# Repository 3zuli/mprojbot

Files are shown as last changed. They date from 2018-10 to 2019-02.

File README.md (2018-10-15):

# mprojbot
MPROJ robot project files

## Development

### Version control with git

Recommendation: Use GitKraken, it's free for personal use.

Main principles:
* master branch is (mostly) stable
* development is done on "feature" (or "topic") branches
* ideal rule: one "feature" = one commit
* avoid merge commits, rebase before merge

#### Feature branch
A "feature" or "topic" branch should concentrate on solving one specific task.
It can be a bug fix, a new feature, or new documentation. This should help
to better split the work for multiple developers and to create less merge
conflicts when integrating the work into the master.

Lifecycle:

1. create a feature branch from the actual master
```sh
git checkout master
git pull origin master
git checkout -b <feature_branch>
```

2. continously commit related changes, rebase to the actual master
```sh
git add ...
git commit -m ...
git pull --rebase origin master
```

3. push the branch to github and create a pull request
```sh
git push --set-upstream origin <feature_branch>
```

4. merge to master
```sh
git checkout master
git merge <feature_branch>
git push
```

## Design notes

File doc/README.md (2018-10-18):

# Place documentation, datasheets, schematics etc. here

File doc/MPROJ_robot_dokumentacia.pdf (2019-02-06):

# Manažment projektov

## Robot pre súťaž Istrobot

Bc. Eduard Mráz

Bc. Adam Trizuljak

Bc. Dominik Varga

Bc. Ondrej Zsíros

Bc. Michal Nagy

Bc. Michal Hubík

# 1 Obsah

1 Obsah | 2
2 Úvod | 3
3 Opis robota | 4
3.1 Vysokoúrovňová časť | 4
3.2 Nízkoúrovňová časť | 4
4 Konštrukcia | 6
5 Nízkoúrovňové riadenie | 10
5.1 Spracovanie senzorov | 10
5.2 Riadenie motorov a odometria | 12
6 Vysokoúrovňové riadenie | 13
6.1 Vizuálny systém robota | 14
6.1.1 Detekcia čiary z obrazu kamery | 14
6.1.2 Určenie regulačnej odchýlky | 15
6.1.2.1 Určenie stredu čiary z obrazu kamery | 16
7 Prepojenie oboch úrovní riadenia | 17
7.1 Komunikačný protokol RPi <-> Nucleo | 18
8 User stories | 19
8.1 User stories riešené v rámci semestra | 19
8.2 Dodatočné user stories pre potreby súťaže Istrobot | 20
9 Záver | 21

# 2 Úvod

Cieľom tohto projektu je navrhnúť, vytvoriť a spojazdniť model robota pre súťaž Istrobot. Súťažnou kategóriou bude Stopár. Robot, ktorý sa zúčastní tejto kategórie by mal byť schopný autonómneho pohybu po určenej dráhe a v časovom limite prísť do cieľa. Smer a trasa je daná tmavým pruhom na bielom podklade, pričom na dráhe sú umiestnené rozličné prekážky, napr. tehla, záclona a mostík. Robot je taktiež limitovaný šírkou a výškou, ktoré nesmú presiahnuť 20 centimetrov.

Výsledkom projektu bude model robota, ktorý bude schopný pohybu po zvolenej dráhe. Bude obsahovať nízko úrovňové a vysoko úrovňové riadenie. Bude obsahovať všetky komponenty potrebné pre zdolanie všetkých prekážok súťaže v danej kategórií. Detegovanie čiary bude zabezpečené pomocou jednoduchého vizuálneho systému.

Nakoľko je súťaž až v nasledujúcom semestri, robot na ňu nemusí byť plne pripravený v čase odovzdávania tohto projektu. A teda ďalšou prácou pre splnenie podmienok súťaže Istrobot, bude tvorba ďalších algoritmov na zdolávanie jednotlivých prekážok.

# 3 Opis robota

Pri návrhu koncepcie sme robota rozdelili na dve základné časti, ktoré medzi sebou komunikujú prostredníctvom sériovej komunikácie, a to vysokoúrovňová časť a nízkoúrovňová časť. Obe tieto časti sú umiestnené na samostatnej doske, kde majú k sebe pripojené senzory potrebné pre súťaž Istrobot.

## 3.1 Vysokoúrovňová časť

Ako už bolo spomenuté robot bude súťažiť v kategórií Stopár, kde musí sledovať čiernu čiaru. Na detekovanie čiary musí byť robot vybavený senzorom, ktorý bude schopný čiaru rozlíšiť oproti bielej podložke. My sme si zvolili kameru RASPBERRY Pi Camera Board, ktorá je doplnená o osvetlenie pre prekážku tunel. Kamera je pripojená cez rozhranie CSI k výpočtovej jednotke Raspberry Pi Model 2.

Okrem výpočtovej jednotky a kamery je vo vysokoúrovňovej časti zabudovaný aj napäťový regulátor, ktorého vstupom je napätie akumulátora a výstupom je stabilizované napätie 5V, ktoré slúži na napájanie RPi a mikroprocesora v nízkoúrovňovej časti. Regulátor je umiestnený zo spodnej strany dosky. Pre lepšiu manipuláciu s robotom sme do vysokoúrovňovej časti umiestnili aj vypínač, ktorý odpája napájanie motorov.

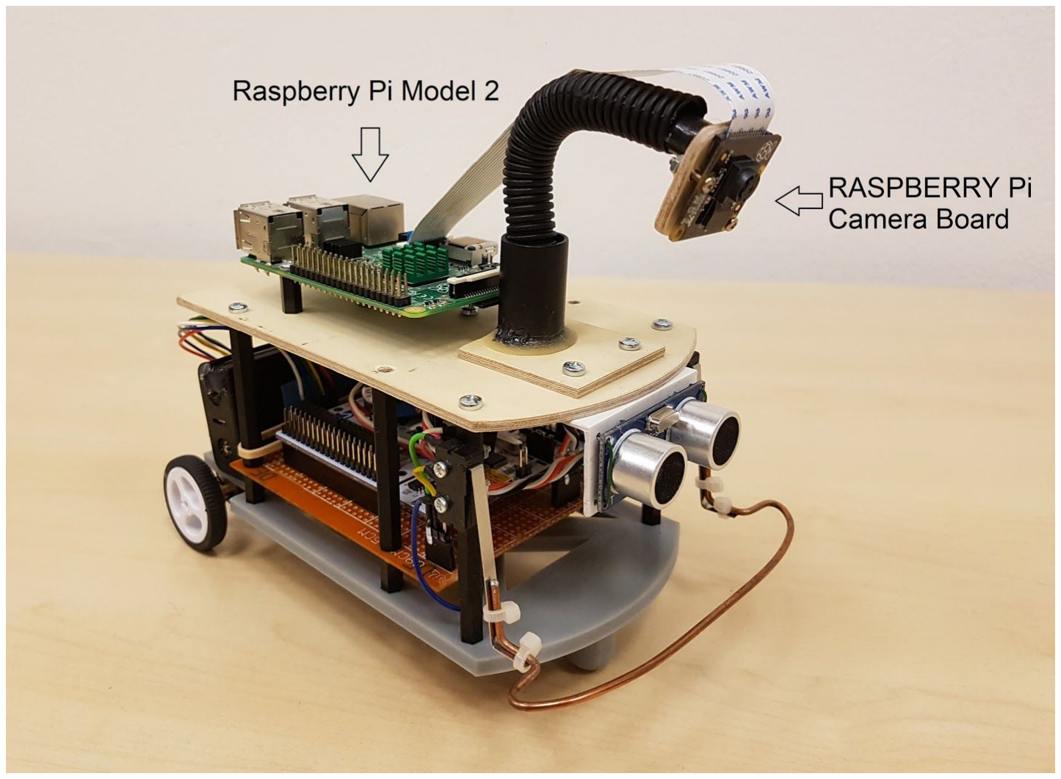
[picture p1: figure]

## 3.2 Nízkoúrovňová časť

Sériovou komunikáciou vysokoúrovňová časť posiela signály do nízkoúrovňovej časti konkrétne do vývojovej jednotky Nucleo64-F411RE, ktoré súčasťou je mikroprocesor

STMicroelectronics STM32F411. V mikroprocesore signály poslané vysokoúrovňovou časťou spracujú a vyhodnotia sa potrebné uhlové rýchlosti otáčania oboch kolies. Signál určujúci veľkosť uhlovej rýchlosti kolies sa pošle do budiča motorov, ktorý reguláciou napájacieho napätia motorov určí ich výslednú rýchlosť otáčania. Regulácia napätia je uskutočňovaná pulzne šírkovou moduláciou.

Keďže jedna z prekážok na súťaži je tehla (tehla položená cez čiernu čiaru) robot musí vedieť obísť túto prekážku. Na to nám slúžia dva typy senzorov - ultrazvukový snímač a tlačidlový spínač na prednom nárazníku. Keď sa robot bude približovať k tehle kamera nebude môcť detekovať čiaru. Robot sa bude pohybovať ďalej ale čím bližšie bude k tehle tým pomalšie pôjde. Toto spomaľovanie spôsobuje ultrazvukový snímač, ktorý spomaľuje robota až kým nepríde k tehle. Akonáhle robot narazí na tehlu zopnú sa tlačidlové spínače na nárazníku a robot začne prekážku obchádzať. Po obídení prekážky kamera znova začne detekovať čiaru a robot pokračuje ako doposiaľ. Na rovnakom princípe sa robot bude pohybovať aj pri prekážke typu záclona, kde robot bude spomaľovať ako sa bude približovať k záclone. Keďže záclona nie je pevná prekážka, tlačidlové snímače sa nezopnú a robot bude pomaly pokračovať cez záclonu až kým sa robot znovu nezrýchli za prekážkou.

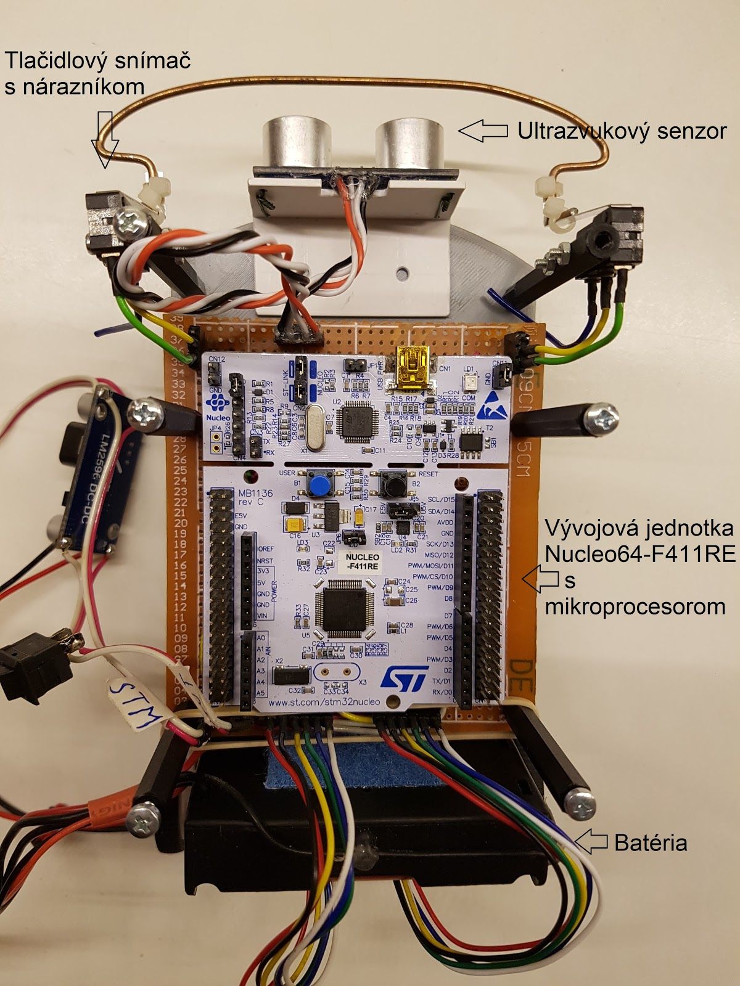
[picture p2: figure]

# 4 Konštrukcia

Po koncepčnom návrhu jednotlivých funkcionalít, potrebných pre úspešné prejdenie celého súťažného kola súťaže Istrobot v kategórii Stopár, vrátane všetkých špecifikovaných prekážok, bolo potrebné navrhnúť fyzickú konštrukciu celého robota.

Najzákladnejším parametrom konštrukcie, ktorý bolo potrebné stanoviť ako prvý, boli vonkajšie rozmery, čiže dĺžka, šírka a výška. Azda najviac limitujúcim faktorom na súťažnej dráhe je prekážka “Tunel”, ktorá má vstupný otvor rozmerov 20x20cm. Pre úspešné prejdenie tejto prekážky je potrebné aby robot vošiel do tunela - jeho šírka a výška musia byť menšie ako 20cm, a zároveň dokázal v neosvetlenom priestore sledovať čiaru. My sme sa rozhodli zvoliť celkovú šírku 12cm. Táto šírka plne postačuje na dostatok priestoru pre všetky komponenty a zároveň poskytuje dostatočnú rezervu pre vstup do tunela bez prípadnej kolízie z dôvodu nepresnosti riadenia. Dĺžku robota sme po rýchlom prototypovaní - pokusné rozmiestňovanie jednotlivých komponentov na čo najmenšej ploche, zvolili 25 centimetrov. Dĺžka robota nie je obmedzená žiadnou prekážkou, no nemala by byť príliš veľká z dôvodu možných problémov napríklad pri obchádzaní prekážky “Tehla” alebo pri prejazde zatáčok s malým polomerom. Na výslednú dĺžku mali vplyv hlavne rozmery riadiacich dosiek, akumulátorov, motorov a nárazníka.

Po stanovení rozmerov bolo potrebné zvoliť typ podvozku robota. Najčastejšie sa v tejto súťaži vyskytujú dvojkolesové alebo štvorkolesové diferenciálne podvozky. Po uvážení faktorov ako napríklad:

- Celková hmotnosť
- Rozmery a potrebná kapacita akumulátorov
- Náročnosť konštrukcie
- Cena komponentov
- Zložitosť riadenia

sme sa rozhodli pre dvojkolesový diferenciálny podvozok v jedným oporným kolesom. Konfigurácia kolies je nasledovná:

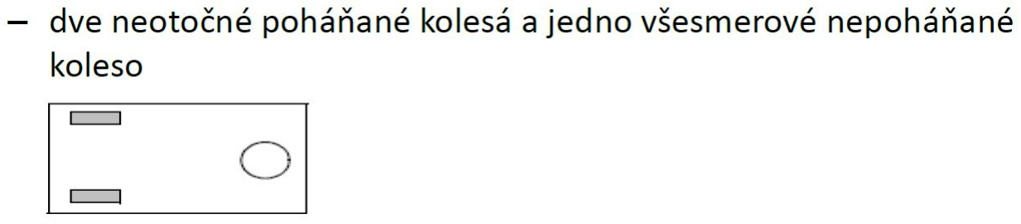
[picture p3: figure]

Po zvolení koncepcie podvozku, bolo potrebné navrhnúť jeho konštrukciu. Po zvážení rôznych konštrukčných požiadaviek sme sa rozhodli vytvoriť základnú podvozkovú dosku formou návrhu 3D modelu a následnej 3D tlače z plastu typu PLA. Voľbou tohto postupu sme zabezpečili nízku hmotnosť, dostatočnú pevnosť a tiež presnosť upevnení motorov. Presnosť bola veľmi dôležitým faktorom, nakoľko sa oba motory (obe osi kolies) musia z dôvodu požadovanej trajektórie podvozku nachádzať na jednej osi. To zabezpečí možnosť priamočiareho pohybu ako aj otáčania na mieste. Okrem dier potrebných k upevneniu motorov obsahuje táto základná doska aj diery potrebné pre uchytenie dištančných stĺpikov. Na tie sa následne montovala doska nízkoúrovňového a vysokoúrovňového riadenia. Zároveň dva predné stĺpiky slúžia aj na uchytenie mikrospínačov nárazníka v požadovanej výške 75 mm od zeme. Na uchytenie vypínačov poslúžili krížové skrutky M2 x 15 mm. K základnej doske je nad osou motorov pripevnený pomocou suchého zipsu pohonný akumulátor tvorený dvoma Li-Ion článkami typu 18650 akumulátorov a pre istotu je jeho pozícia fixovaná pomocou gumičky o zadné dištančné stĺpiky.

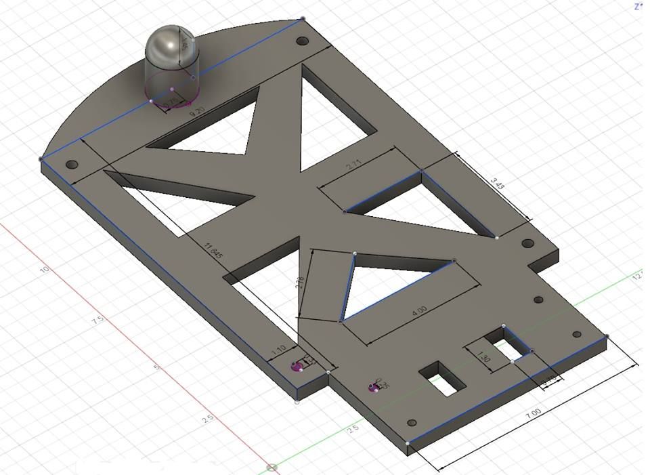
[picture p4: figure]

3D CAD model podvozku robota

Po vytlačení a opracovaní hrán základnej dosky sme ako prvé pripevnili motory - konkrétne sme zvolili jednosmerné motory s nasledovnými parametrami:

- Rýchlosť: 90 otáčok/min.
- Napájacie napätie: 6V
- Prevodový pomer prevodovky: 100:1
- Krútiaci moment (kg.cm): 0.7
- Elektrický prúd (mA): ≤170
- Počet impulzov na jednu otáčku kolesa: 2800

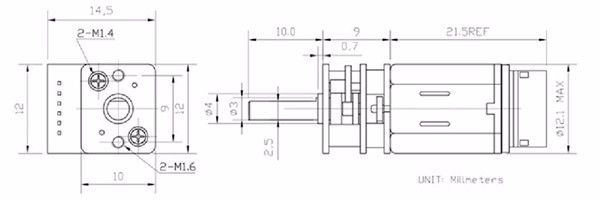
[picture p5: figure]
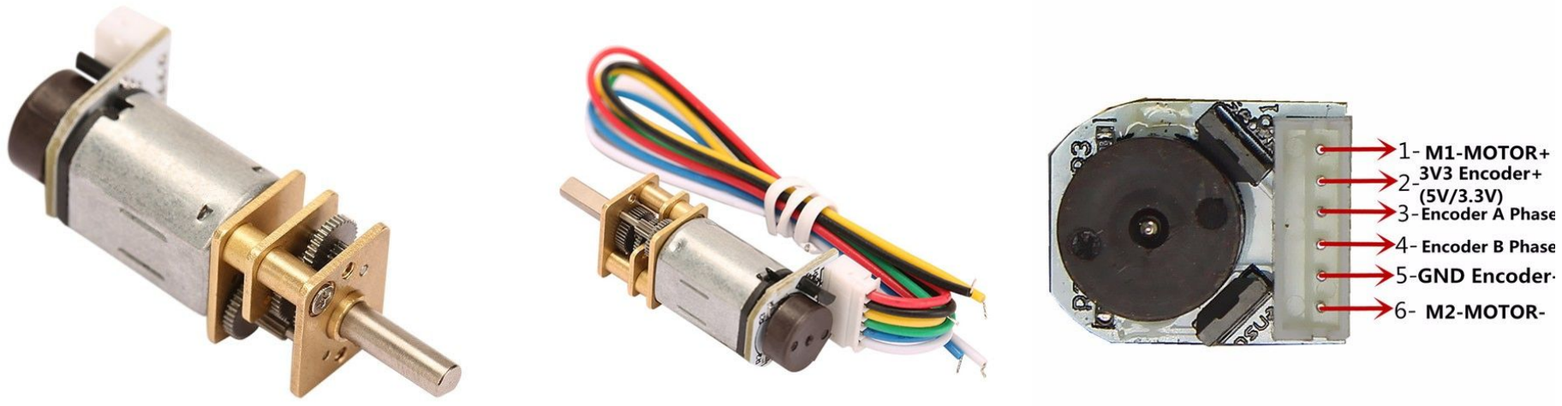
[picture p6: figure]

Po primontovaní kolies s priemerom 35mm na hriadele prevodovky bol v podstate dokončený celý podvozok. Následne sme na základnú dosku pripevnili prvé dištančné stĺpiky s dĺžkou 11 mm na ktoré bola upevnená univerzálna doska plošných spojov - DPS, s rozmermi 10 x 9 centimetrov. Táto doska - nazývaná aj ako “doska nízkoúrovňového riadenia”, obsahuje:

- Päticu pre mikrokontrolér
- Mikrokontrolér STM Nucleo F411RE
- 2x dolnopriepustný filter pre spínače nárazníka
- Napájacie a komunikačné konektory
- Driverovú dosku zabezpečujúcu chod motorov
- Kabeláž periférii k nízkoúrovňovému mikrokontroléru

Keďže by sa na jedno podlažie robota všetky potrebné súčiastky nezmestili, bolo potrebné navrhnúť a vyrobiť aj druhé podlažie, kam by sa umiestnili zvyšné súčiastky.

Ako nosnú konštrukciu druhého podlažia robota sme opäť zvolili plastové dištančné stĺpiky dĺžky 50mm, na ktoré sme umiestnili z leteckej preglejky hrúbky 3mm vyrezávanú dosku v tvare základnej dosky podvozku. Dosku druhého podlažia nazývame aj doska vysokoúrovňového riadenia. Do nej sme následne vŕtaním vyrobili diery potrebné pre uchytenie následných komponentov:

- Napäťový regulátor
- Mikropočítač Raspberry Pi 2
- Kolískový vypínač napájania motorov
- Držiak vizuálneho systému + vizuálny systém

- Ultrazvukový senzor

Použitý napäťový regulátor LM2596 DC-DC slúži na konvertovanie vstupného jednosmerného napätia z akumulátora na stabilizované napätie 5V potrebné na napájanie oboch dosiek riadenia. Jeho uchytenie je realizované dištančnými stĺpikmi. Kolískový vypínač umiestnený vedľa mikropočítača Raspberry Pi z hornej strany dosky slúži na prerušenie napájania driverovej dosky - robot sa prestane hýbať. Držiak kamery je umiestnený v prednej časti hornej dosky, a poskytuje 6 stupňov voľnosti pri nastavovaní polohy a orientácie kamery. Kamera je k držiaku pripevnená dvomi krížovými skrutkami M2x20 mm Na záver je horná doska upevnená k dištančným stĺpikom krížovými skrutkami M3 x 20mm.

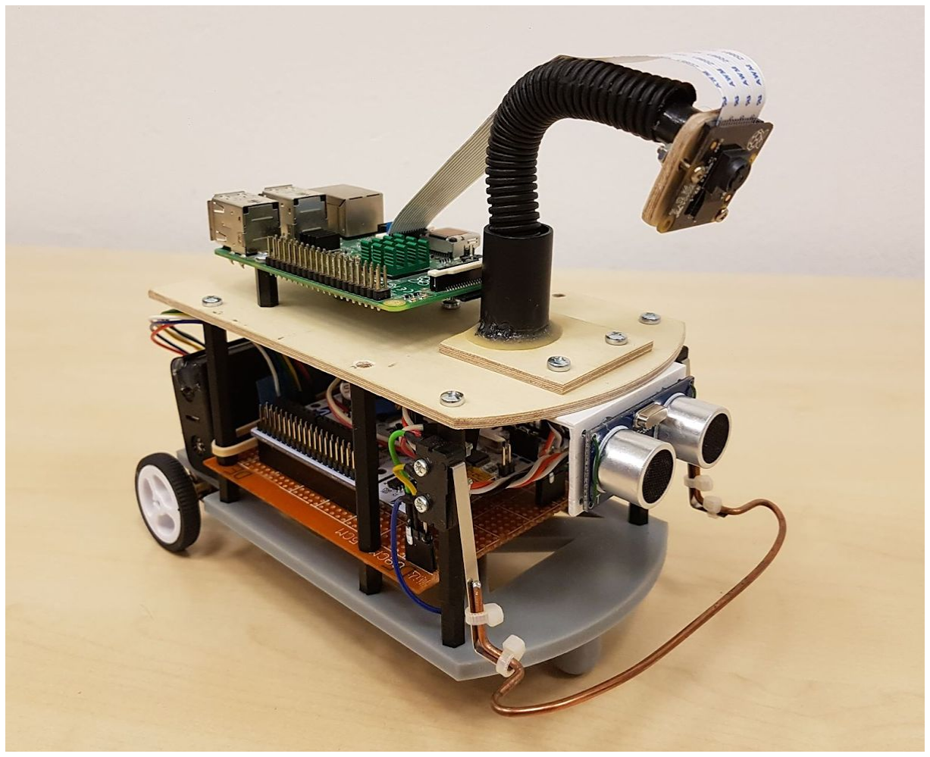
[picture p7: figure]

# 5 Nízkoúrovňové riadenie

Nízkoúrovňové riadenie prijíma príkazy z vysokoúrovňového riadenia prebiehajúceho v Raspberry Pi a zabezpečuje predovšetkým riadenie rýchlosti motorov. Taktiež počíta aktuálnu odometriu, spracováva údaje zo senzorov a odosiela ich do Raspberry Pi, kde prebieha ich vyhodnotenie.

Riadenie je realizované mikroprocesorom STMicroelectronics STM32F411 (ďalej len STM), čo je 32-bitový ARM Cortex-M4 procesor s frekvenciou 100MHz, s 512KB programovej pamäte a 128KB RAM. Tento procesor je súčasťou vývojovej dosky Nucleo64-F411RE, ktorá obsahuje aj programátor/debugger s USB rozhraním pre jednoduché a pohodlné programovanie.

Po spracovaní senzorov sa výsledné údaje spolu s údajmi odometrie odosielajú po sériovej linke do Raspberry Pi.

## 5.1 Spracovanie senzorov

Mikroprocesor realizuje spracovanie dát z nasledovných senzorov:

- 2x inkrementálny enkóder snímajúci otáčky motorov
- 2x tlačidlový spínač predného nárazníku
- Ultrazvukový senzor vzdialenosti HC-SR04

Tlačidlá nárazníku sú pripojené na dva digitálne vstupy. Program v hlavnej riadiacej slučke periodicky číta ich logické hodnoty (0/1).

Inkrementálne enkódery merajú aktuálnu rýchlosť otáčania motorov, ktorá sa používa na PID reguláciu rýchlosti a výpočet odometrie. Enkódery generujú 7 pulzov na otáčku motora, čo na výstupe prevodovky 100:1 dáva 700 pulzov na otáčku kolesa. Tieto pulzy sú automaticky počítané časovačmi TIM4 a TIM5, ktoré sú použité v režime enkóderového rozhrania. Časovače sú nastavené na režim snímania 4x (počíta sa nábežná aj dobežná hrana oboch signálov enkóderu), celkovo teda máme rozlíšenie 2800 pulzov na otáčku kolesa. Uhlovú rýchlosť motorov získame z rozdielu aktuálnej a predošlej hodnoty časovača.

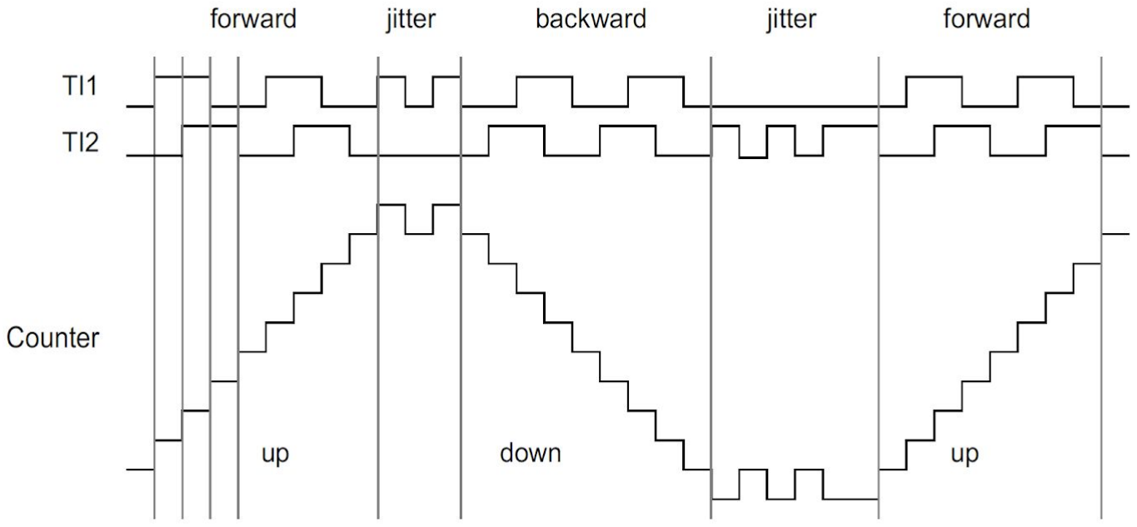
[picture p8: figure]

Hodnota časovača v režime enkóderového rozhrania. TI1,2 - kvadratúrny výstup enkódera, Counter - hodnota počítadla

Výstup ultrazvukového senzora je pulz (ECHO), ktorého dĺžka je rovnaká ako čas od vyslania ultrazvukového pulzu po jeho prijatie. Na presné meranie času je použitý časovač TIM2 v režime počítania nahor s frekvenciou 10MHz, čo zodpovedá časovému rozlíšeniu 0.1μs. Funkcia pre meranie vzdialenosti najprv vyšle do senzoru štartovací pulz (TRIGGER) s dĺžkou 10μs. Následne sa v prerušení čaká na nábežnú hranu signálu ECHO, kde sa vynuluje a spustí časovač. S príchodom dobežnej hrany sa v prerušení zastaví časovač TIM2 a z jeho hodnoty (TIM2CNT) sa vypočíta nameraná vzdialenosť v metroch podľa vzťahu

d = 58000

TIM2CNT

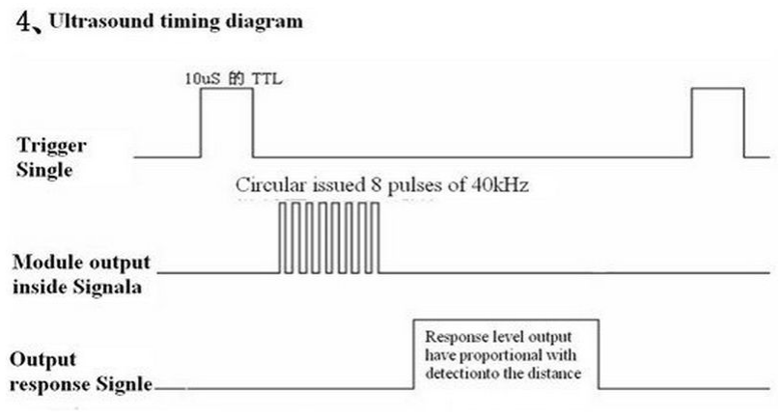
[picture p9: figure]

Časový priebeh komunikácie ultrazvukového senzoru

## 5.2 Riadenie motorov a odometria

Kvôli meniacemu sa napätiu batérie a rôznemu sklonu trate (na mostíku) je potrebné zabezpečiť aktívne spätnoväzobné riadenie rýchlosti motorov. Na tento účel je použitý PID regulátor rýchlosti motorov.

Výstupom vysokoúrovňového riadenia je požadovaná dopredná rýchlosť v a uhlová rýchlosť ω . Z toho vypočítame žiadané uhlové rýchlosti ľavého a pravého motora ωL

, ωR podľa
vzťahov

kde d je vzdialenosť kolies od ťažiska robota a r je polomer kolies.

Riadenie prebieha s frekvenciou 250Hz a je vykonávané pre oba motory samostatne. Vstupom je žiadaná rýchlosť kolesa v radiánoch za sekundu a aktuálna rýchlosť motora získaná z enkóderov, z ktorých sa vypočíta regulačná odchýlka. Hodnota integračnej zložky regulátora je obmedzená na rozsah (-1;1), aby sa zabránilo windupu. Výstupom je bezrozmerný riadiaci signál u v rozsahu (-1;1), kde 0 znamená zastavené motory, 1 je maximálna rýchlosť vpred a -1 je maximálna rýchlosť vzad. Táto hodnota je následne prepočítaná na číslo v rozsahu (0;4095), ktoré udáva striedu pulzne šírkovej modulácie (PWM), ktorou je ovládaná rýchlosť motorov. Celková schéma regulátora je na nasledujúcom obrázku.

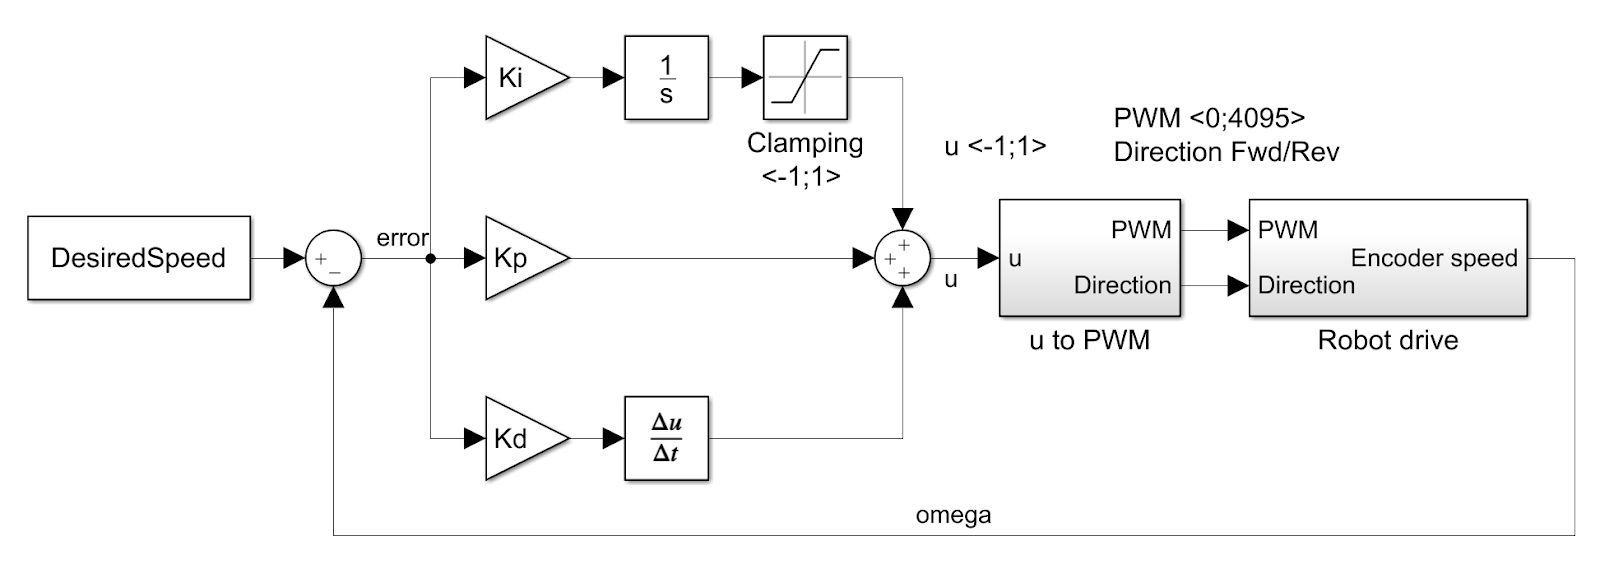
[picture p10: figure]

Schéma PID regulátora rýchlosti motorov

Súčasne s regulátorom prebieha aj výpočet odometrie. Odometria poskytuje odhad aktuálnej polohy a otočenia robota v priestore na základe rýchlosti otáčania kolies. Na nasledujúcom obrázku je znázornená kinematická štruktúra dvojkolesového diferenciálneho podvozku, kde
v je dopredná rýchlosť, φ je aktuálny uhol otočenia, | je vzdialenosť kolies, | je polomer R | d | R
kolies, | sú uhlové rýchlosti motorov a xR
, yR ω , ω | sú aktuálne súradnice ťažiska robota. L | R

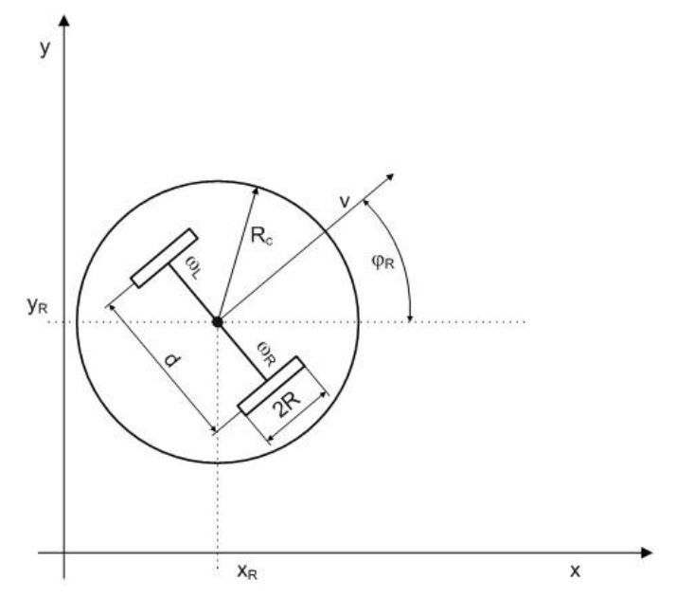
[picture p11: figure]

Výpočet odometrie je realizovaný nasledovnými vzťahmi:

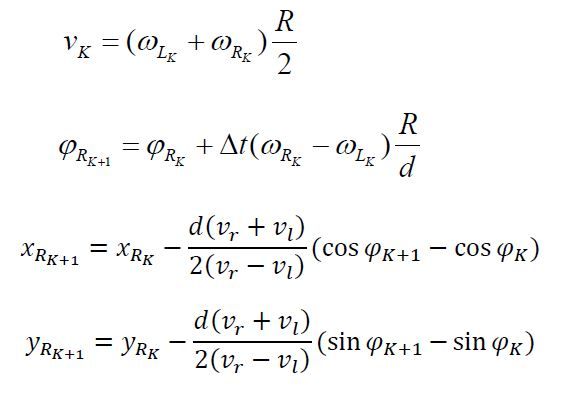
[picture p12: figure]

V prípade, ak sú obe rýchlosti motorov rovnaké:

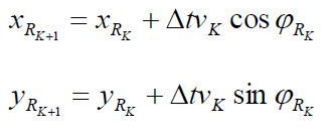
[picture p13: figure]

# 6 Vysokoúrovňové riadenie

Náš robot používa vizuálny systém, a teda pracuje s videom v pomerne vysokej frekvencii. Zatiaľ je FPS (z ang. Frames Per Second - snímky za sekundu - frekvencia spracovania obrazu) nastavené na hodnotu 10. Kvôli tomuto je nutné použiť ďalšiu výpočtovú jednotku, keďže mikroprocesor, ktorý zabezpečuje nízko-úrovňové riadenie by takáto úlohu nezvládal.

Ako výpočtovú jednotku pre vysoko úrovňové riadenie sme zvolili Raspberry Pi Model 2 (ďalej v dokumente len RPi). disponuje procesorom so štyrmi jadrami o takte 900 MHz a 1 GB operačnej pamäte.

V tejto úrovni riadenia budú riešené nasledovné úlohy:

- Spracovanie obrazu z kamery
- Detekcia čiary z obrazu kamery
- Riadiaci algoritmus - výpočet regulačnej odchýlky a výpočet akčného zásahu

## 6.1 Vizuálny systém robota

Vizuálny systém robota je pomerne jednoduchý, keďže ako senzor používa len jeden prvok, a tým je kamera, ktorá je pripojená k RPi. Kamera, ktorú náš systém využíva má názov RASPBERRY Pi Camera Board a je to kamera určená na používanie priamo s RPi. K RPi sa pripája pomocou rozhrania CSI. Dokáže vyhotoviť video s FULL HD rozlíšením a 30 FPS. Tieto parametre su pre nás plne postačujúce, keďže hodnoty FPS aj rozlíšenie sú v našom prípade nižšie - rozlíšenie používame 320x240px a FPS s hodnotou 10.

Ako nástroj pre softvérový prístup ku kamere a získanie snímok z nej používame známu knižnicu OpenCV v prostredí programovacieho jazyka Python. Detekciu čiary na snímkach z kamery taktiež realizujeme pomocou nástrojov z knižnice OpenCV.

### 6.1.1 Detekcia čiary z obrazu kamery

Čiaru z obrazu kamery dokážeme pomerne jednoducho identifikovať pomocou klasických deterministických metód počítačového videnia. Je to najmä vďaka faktu, že pri kategórii LineFollower v súťaži Istrobot je čiara viditeľná veľmi zreteľne - čiara je čierna na čisto bielom podklade.

v prvej fáze tejto úlohy potrebujeme vytvoriť binárnu masku, kde biele pixely (pixely s hodnotou 1) budú predstavovať časť obrazu, kde sa nachádza čiara. Ostatné pixely budú čierne (s hodnotou 0). Toto dosiahneme aplikovaním nasledujúcich krokov (poradie je dôležité, čísla predstavujú poradie):

1. Konverzia snímku na čiernobiely (pixel má len jeden parameter - intenzitu)
2. Ignorovanie pixelov, ktoré majú intenzitu mimo definovaný rozsah - rozsah sa volí v závislosti od svetelných podmienok, svetelnej odrazivosti podkladu atď.
3. Dilatácia snímku
4. Nájdenie kontúr, pomocou funkcie findContours z knižnice OpenCV
5. Výpočet plochy všetkých nájdených kontúr pomocou funkcie contourArea z knižnice OpenCV
6. Ponechanie kontúry s najväčšou plochou - predpokladáme, že najväčší objekt na obraze je sledovaná čiara

V tomto momente máme identifikovanú kontúru sledovanej čiary a pomocou funkcie fillPoly dokážem splniť vyššie spomínaný cieľ tejto úlohy.

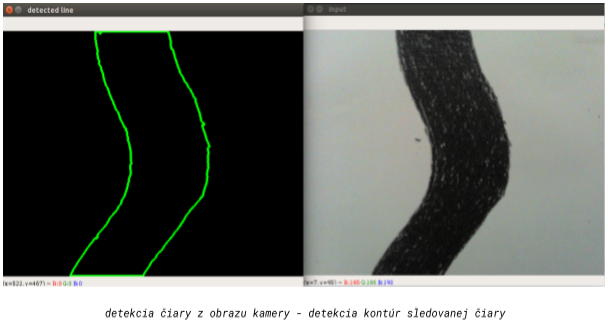
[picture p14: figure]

### 6.1.2 Určenie regulačnej odchýlky

V predchádzajúcom kroku sme dokázali určiť polohu všetkých pixelov obrazu, na ktorých sa nachádza sledovaná čiara. Stále však potrebujeme kvantifikovať jednotnú regulačnú odchýlku ako skalár, na základe ktorej pošleme do nízkej úrovne riadenia riadiaci zásah. Ako regulačnú odchýlku sme zvolili vzdialenosť stredu čiary v línii stredu snímku od samotného stredu snímku. Pre ilustráciu:

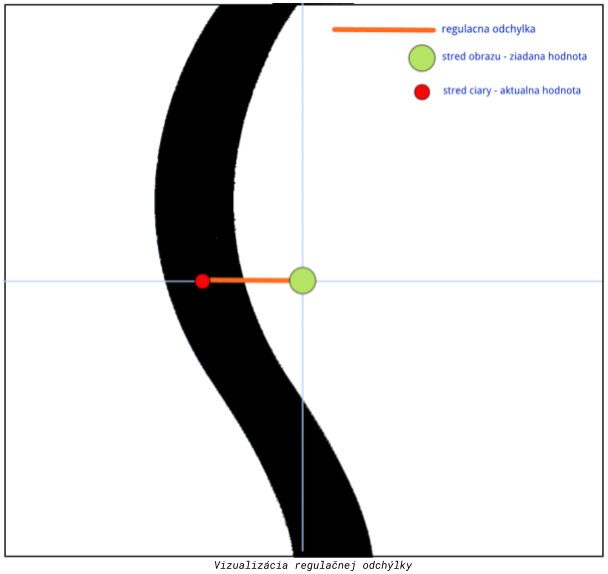
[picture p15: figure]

6.1.2.1 Určenie stredu čiary z obrazu kamery
V predchádzajúcej sekcii sme jasne pomenovali a určili regulačnú odchýlku - hodnotu, ktorú sa budeme snažiť minimalizovať. Pri implementácii sme však riešili problém, ako určiť stred čiary v línii stredu obrazu - aktuálnu hodnotu - červená kružnica na obrázku vyššie.

Počítame s tým, že poznáme všetky pixely, ktoré tvoria kontúru čiary, a tak urobíme nasledovnú postupnosť krokov:

### 1. Iterujeme všetky body kontúry čiary 2. Ak bod kontúry má y súradnicu (výšku) v intervale +-3 pixely polovice výšky

obrazu, pridajme tento bod do listu nájdených bodov

### 3. Urobíme priemer súradníc všetkých nájdených bodov z kroku 2

# 7 Prepojenie oboch úrovní riadenia

Na začiatok si uvedieme schému fungovania celého riadenia robota.

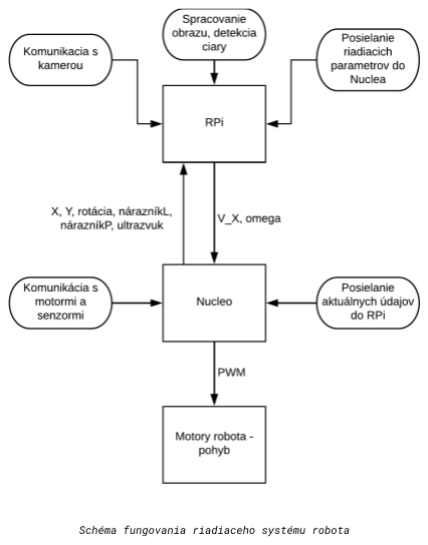
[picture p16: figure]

Zo schémy vidíme základné fungovanie systému, no potrebujeme ešte doplniť pár informácií, aby bolo zrejmé, ako RPi a Nucleo spolu komunikujú:

- RPi a Nucleo na komunikáciu medzi sebou používajú UART
- Je definovaný nemenný formát správ - komunikačný protokol (uvedený bude nižšie)

## 7.1 Komunikačný protokol RPi <-> Nucleo

Pre správne fungovanie komunikácie medzi RPi a Nucleo musíme definovať komunikačný protokol.

- Prenos. rýchlosť 112500baud
- Protokol je definovaný ako textový - človekom čitateľný
- Premenná obsahujúca správu je string
- Ukončovací znak - ‘/n’, po jeho prijatí sa spracuje to, čo je prijaté v bufferi
- Formát správy, ktorý sa posiela z RPi do Nuclea
- "v_x[-1..1%.3f],omega[-1..1%.3f]\n"
■ v_x - žiadaná dopredná rýchlosť (m/s)
■ omega - žiadaná uhlová rýchlosť (rad/s)
- Formát správy, ktorý sa posiela z Nuclea do RPi
- "OdomX[float%.4f],OdomY[float%.4f],OdomRot[float%.4f],BumperL[0 /1int],BumperR[0/1int],ultrasound[float%.2f]\n"
■ OdomX - aktuálna súradnica X podľa odometrie (m)
■ OdomY - aktuálna súradnica Y podľa odometrie (m)
■ OdomRot - aktuálna rotácia podľa odometrie (rad)
■ BumperL - informácia, či je ľavý nárazník v kontakte s prekážkou ■ BumperR - informácia, či je pravý nárazník v kontakte s prekážkou ■ ultrasound - vzdialenosť prekážky pred robotom, údaj z ultrazvuku (m)
- 0.0-2.0m: platný údaj
- < 0: neplatný údaj (mimo rozsah)

# 8 User stories

## 8.1 User stories riešené v rámci semestra

AKO | MUSÍM | ABY SOM | MIERA SPLNENIA
Robot | spĺňať pravidlá súťaže Istrobot v kategórií Stopár | sa mohol zúčastniť | 100%
Robot | mať konštrukciu | mal podvozok a moje komponenty mali miesto | 100%
Robot | mať mikroprocesor (STM32 Nucleo) | mal nízko úrovňové riadenie | 100%
Robot | mať Raspberry Pi | vysoko úrovňový prístup (kamera, riadiace príkazy) | 100%
Robot | mať kameru | vedel detegovať čiaru s dostatočným rozlíšením | 100%
Robot | čítať enkódery | mal funkčnú odometriu a reguláciu rýchlosti | 100%
Robot | mať batérie | mal zdroj energie | 100%
Robot | mať motory a kolesá | bol schopný pohybu | 100%
Robot | mať nárazník so spínačom | vedel že narazil do prekážky | 100%
Robot | mať senzor vzdialenosti | mohol detegovať prekážku pred sebou | 100%
Robot | spätnoväzobné riadenie rýchlosti motorov | vedel presne riadiť smer a dokázal vyjsť na rampu | 100%
Robot | počítať odometriu | vedel určiť svoju polohu a prejdenú vzdialenosť | 90%
Robot | komunikačný protokol | si medzi RPI a Nucleo vedel vymieňať informácie | 100%

Robot | mať tlačítko na spustenie motorov | sa vedel pohnúť | 100%
RPI a Nucleo | byť prepojené cez sériový port | vedeli navzájom komunikovať | 100%
RPi | detegovať čiaru z kamery | vedel riadiť sledovanie čiary | 95%
RPi | mať nainštalované knižnice (OpenCV, piCamera) | vedel vyvíjať algoritmy pre sledovanie čiary | 100%
RPi | dávať jednoznačnú odchýlku od čiary | vedel robot jednoznačne riadiť | 100%
Súťažiaci | odštartovať robota | sa mohol zúčastnil súťaže | 100%

## 8.2 Dodatočné user stories pre potreby súťaže Istrobot

AKO | MUSÍM | ABY SOM
Robot | mať algoritmus | obišiel prekážku tehla
Robot | mať algoritmus | prešiel prekážku olejová škvrna

# 9 Záver

Počas semestra sme dokázali doviesť projekt Stopára do štádia, kedy je všetko plne pripravené na samotný, čistý softvérový vývoj pokročilých riadiacich algoritmov sledovania čiary pomocou robota. To znamená (kompletná funkcionalita sa nachádza v User Stories):

- je pripravená platforma pre vizuálny systém, tj. prístup ku kamere práca s obrazom, je navrhnutý prvý prototyp sledovania čiary
- z vyššej vrstvy riadenia dokážeme posielať riadiace príkazy, a tým generovať ľubovoľnú trajektóriu
- údaje zo všetkých senzorov sú k dispozícii pre vývojárov, a to vrátane odometrie - už robot zastaví, ak je pred ním prekážka (podľa ultrazvuku)
- komunikácia medzi RPi a Nucleo je vyriešená
- kompletne vyriešená je konštrukcia, mechanické časti robota a elektronika

V rámci predmetu Manažment Projektov sme si taktiež vyskúšali agílny manažment tohto projektu. Každý týždeň sme absolvovali šprinty, kde sme sumarizovali, koľko práce sme za konkrétny šprint stihli, resp. nestihli. Taktiež sme plánovali do budúcna a snažili sa smerovať projekt tak, aby sme stíhali každý jeden šprint dodať dohodnutý výstup. Nástroje, ktoré nám pri agílnom vývoji pomohli, boli:

- Slack/Facebook group chat - komunikačné nástroje
- Trello - manažment úloh
- Google Docs/Sheets - nástroje na tvorbu dokumentov online, umožňujúce kolaboráciu
- Git - verzionovací systém, kde sme postupne zverejňovali svoje zdrojové kódy tak, aby ich mal každý k dispozícii. Repozitár je k dispozícii na adrese https://github.com/3zuli/mprojbot

Výsledok hodnotíme ako dobrý a sme s ním spokojní. Počas agílneho vývoja sme sa zhodli, že našim cieľom bude “rozhýbať” robot, tj. že robot bude schopný hýbať sa na základe riadiacich pokynov z vyššej vrstvy riadenia. Toto má za dôsledok, že sme sa ocitli v štádiu, kedy si ktokoľvek robota vezme domov a môže na ňom skúšať vyvíjať rôzne algoritmy. Nepotrebuje k tomu znalosti napríklad z vnorených systémov (nízka úroveň riadenia). Tým pádom si myslíme, že takto vytvoríme lepšiu možnosť paralelizácie ďalšieho vývoja a zvýšime tým naše šance, čo najlepšie sa umiestniť v súťaži Istrobot.

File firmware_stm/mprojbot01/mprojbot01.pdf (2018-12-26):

## mprojbot01 Project Configuration Report

# 1. Description

## 1.1. Project

Project Name | mprojbot01
Board Name | NUCLEO-F411RE
Generated with: | STM32CubeMX 4.23.0
Date | 12/26/2018

## 1.2. MCU

MCU Series | STM32F4
MCU Line | STM32F411
MCU name | STM32F411RETx
MCU Package | LQFP64
MCU Pin number | 64

# 2. Pinout Configuration

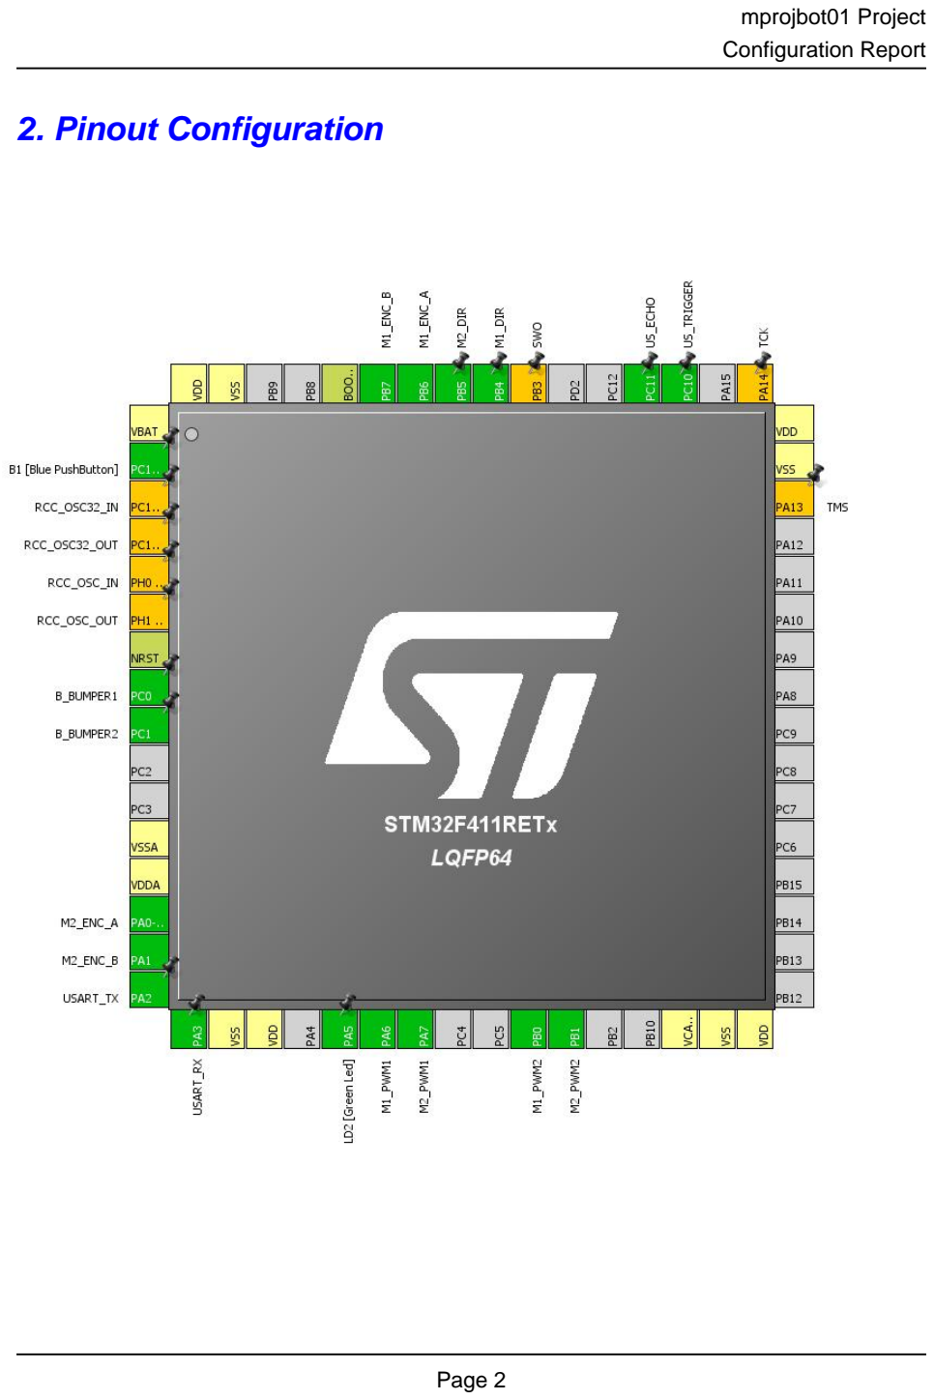
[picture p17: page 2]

# 3. Pins Configuration

Pin Number LQFP64 | Pin Name (function after reset) | Pin Type | Alternate Function(s) | Label
1 | VBAT | Power
2 | PC13-ANTI_TAMP | I/O | GPIO_EXTI13 | B1 [Blue PushButton]
3 | PC14-OSC32_IN * | I/O | RCC_OSC32_IN
4 | PC15-OSC32_OUT * | I/O | RCC_OSC32_OUT
5 | PH0 - OSC_IN * | I/O | RCC_OSC_IN
6 | PH1 - OSC_OUT * | I/O | RCC_OSC_OUT
7 | NRST | Reset
8 | PC0 ** | I/O | GPIO_Input | B_BUMPER1
9 | PC1 ** | I/O | GPIO_Input | B_BUMPER2
12 | VSSA | Power
13 | VDDA | Power
14 | PA0-WKUP | I/O | TIM5_CH1 | M2_ENC_A
15 | PA1 | I/O | TIM5_CH2 | M2_ENC_B
16 | PA2 | I/O | USART2_TX | USART_TX
17 | PA3 | I/O | USART2_RX | USART_RX
18 | VSS | Power
19 | VDD | Power
21 | PA5 ** | I/O | GPIO_Output | LD2 [Green Led]
22 | PA6 | I/O | TIM3_CH1 | M1_PWM1
23 | PA7 | I/O | TIM3_CH2 | M2_PWM1
26 | PB0 | I/O | TIM3_CH3 | M1_PWM2
27 | PB1 | I/O | TIM3_CH4 | M2_PWM2
30 | VCAP1 | Power
31 | VSS | Power
32 | VDD | Power
46 | PA13 * | I/O | SYS_JTMS-SWDIO | TMS
47 | VSS | Power
48 | VDD | Power
49 | PA14 * | I/O | SYS_JTCK-SWCLK | TCK
51 | PC10 ** | I/O | GPIO_Output | US_TRIGGER
52 | PC11 | I/O | GPIO_EXTI11 | US_ECHO
55 | PB3 * | I/O | SYS_JTDO-SWO | SWO
56 | PB4 ** | I/O | GPIO_Output | M1_DIR
57 | PB5 ** | I/O | GPIO_Output | M2_DIR
58 | PB6 | I/O | TIM4_CH1 | M1_ENC_A
59 | PB7 | I/O | TIM4_CH2 | M1_ENC_B

Pin Number LQFP64 | Pin Name (function after reset) | Pin Type | Alternate Function(s) | Label
60 | BOOT0 | Boot
63 | VSS | Power
64 | VDD | Power

## ** The pin is affected with an I/O function * The pin is affected with a peripheral function but no peripheral mode is activated

# 4. Clock Tree Configuration

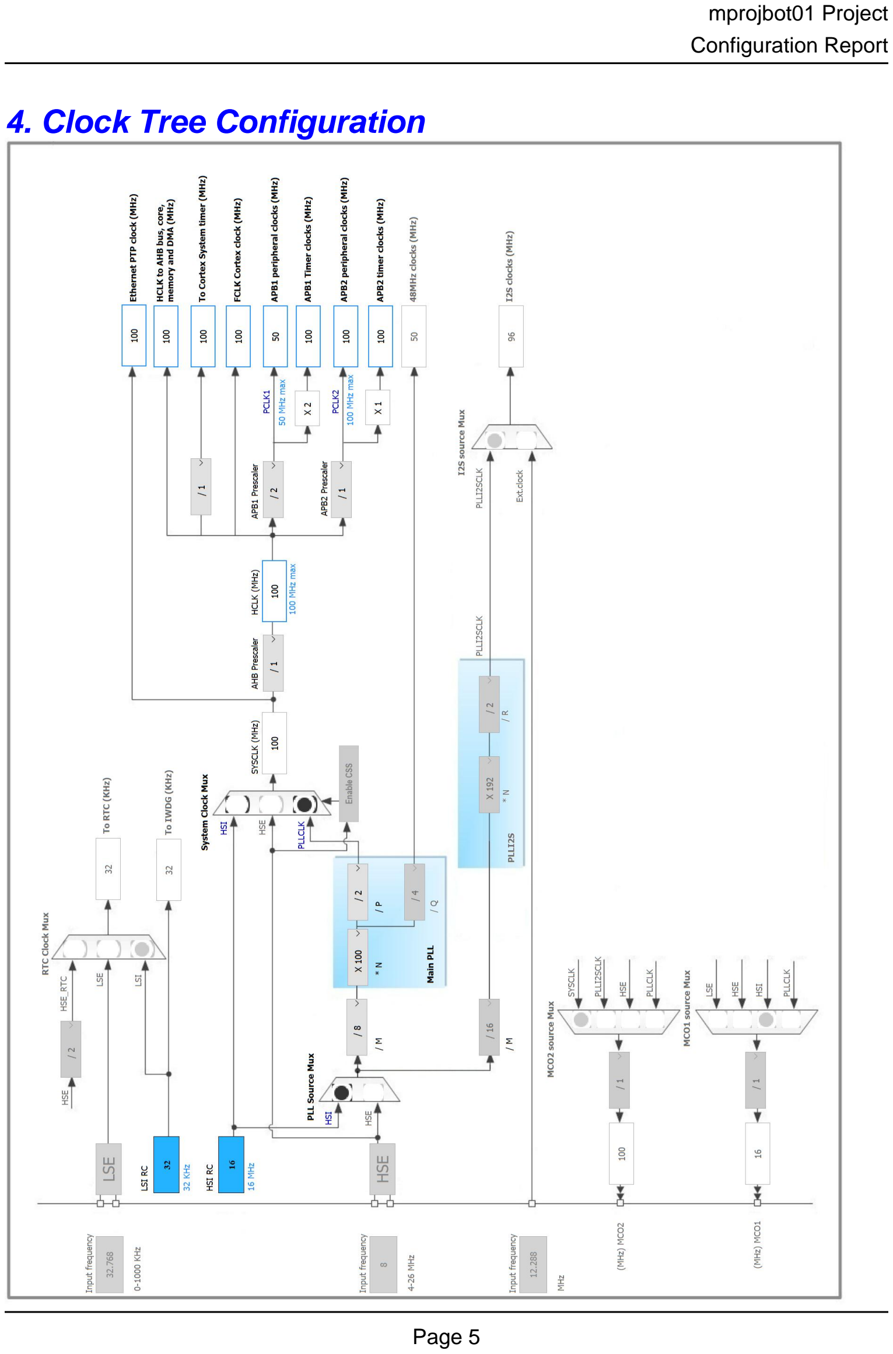
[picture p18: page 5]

# 5. IPs and Middleware Configuration

# 5.1. SYS

## Timebase Source: SysTick

# 5.2. TIM2

## Clock Source : Internal Clock

## 5.2.1. Parameter Settings:

### Counter Settings:

Prescaler (PSC - 16 bits value) | 10 *
Counter Mode | Up
Counter Period (AutoReload Register - 32 bits value ) | 4294967295 *
Internal Clock Division (CKD) | No Division

### Trigger Output (TRGO) Parameters:

Master/Slave Mode | Disable (no sync between this TIM (Master) and its Slaves
Trigger Event Selection | Reset (UG bit from TIMx_EGR)

# 5.3. TIM3

## Channel1: PWM Generation CH1 Channel2: PWM Generation CH2 Channel3: PWM Generation CH3 Channel4: PWM Generation CH4

## 5.3.1. Parameter Settings:

### Counter Settings:

Prescaler (PSC - 16 bits value) | 0
Counter Mode | Up
Counter Period (AutoReload Register - 16 bits value ) | 4096 *
Internal Clock Division (CKD) | No Division

### Trigger Output (TRGO) Parameters:

Master/Slave Mode | Disable (no sync between this TIM (Master) and its Slaves
Trigger Event Selection | Reset (UG bit from TIMx_EGR)

### PWM Generation Channel 1:

Mode | PWM mode 1
Pulse (16 bits value) | 0
Fast Mode | Disable
CH Polarity | High

### PWM Generation Channel 2:

Mode | PWM mode 1
Pulse (16 bits value) | 0
Fast Mode | Disable
CH Polarity | High

### PWM Generation Channel 3:

Mode | PWM mode 1
Pulse (16 bits value) | 0
Fast Mode | Disable
CH Polarity | High

### PWM Generation Channel 4:

Mode | PWM mode 1
Pulse (16 bits value) | 0
Fast Mode | Disable
CH Polarity | High

# 5.4. TIM4

## Combined Channels: Encoder Mode

## 5.4.1. Parameter Settings:

### Counter Settings:

Prescaler (PSC - 16 bits value) | 0
Counter Mode | Up
Counter Period (AutoReload Register - 16 bits value ) | 65535 *
Internal Clock Division (CKD) | No Division

### Trigger Output (TRGO) Parameters:

Master/Slave Mode | Disable (no sync between this TIM (Master) and its Slaves
Trigger Event Selection | Reset (UG bit from TIMx_EGR)

### Encoder:

Encoder Mode | Encoder Mode TI1 and TI2 *

____ Parameters for Channel 1 ____
Polarity | Rising Edge
IC Selection | Direct

Prescaler Division Ratio | No division
Input Filter | 0
____ Parameters for Channel 2 ____
Polarity | Rising Edge
IC Selection | Direct
Prescaler Division Ratio | No division
Input Filter | 0

# 5.5. TIM5

## Combined Channels: Encoder Mode

## 5.5.1. Parameter Settings:

### Counter Settings:

Prescaler (PSC - 16 bits value) | 0
Counter Mode | Up
Counter Period (AutoReload Register - 32 bits value ) | 65535 *
Internal Clock Division (CKD) | No Division

### Trigger Output (TRGO) Parameters:

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

### Encoder:

Encoder Mode | Encoder Mode TI1 and TI2 *

____ Parameters for Channel 1 ____
Polarity | Rising Edge
IC Selection | Direct
Prescaler Division Ratio | No division
Input Filter | 0
____ Parameters for Channel 2 ____
Polarity | Rising Edge
IC Selection | Direct
Prescaler Division Ratio | No division
Input Filter | 0

# 5.6. USART2

## Mode: Asynchronous

## 5.6.1. Parameter Settings:

### Basic Parameters:

Baud Rate | 115200
Word Length | 8 Bits (including Parity)
Parity | None
Stop Bits | 1

### Advanced Parameters:

Data Direction | Receive and Transmit
Over Sampling | 16 Samples

### * User modified value

# 6. System Configuration

# 6.1. GPIO configuration

IP | Pin | Signal | GPIO mode | GPIO pull/up pull down

## Max Speed

## User Label

TIM3 | PA6 | TIM3_CH1 | Alternate Function Push Pull | No pull-up and no pull-down | Low | M1_PWM1
| PA7 | TIM3_CH2 | Alternate Function Push Pull | No pull-up and no pull-down | Low | M2_PWM1
| PB0 | TIM3_CH3 | Alternate Function Push Pull | No pull-up and no pull-down | Low | M1_PWM2
| PB1 | TIM3_CH4 | Alternate Function Push Pull | No pull-up and no pull-down | Low | M2_PWM2
TIM4 | PB6 | TIM4_CH1 | Alternate Function Push Pull | No pull-up and no pull-down | Low | M1_ENC_A
| PB7 | TIM4_CH2 | Alternate Function Push Pull | No pull-up and no pull-down | Low | M1_ENC_B
TIM5 | PA0-WKUP | TIM5_CH1 | Alternate Function Push Pull | No pull-up and no pull-down | Low | M2_ENC_A
| PA1 | TIM5_CH2 | Alternate Function Push Pull | No pull-up and no pull-down | Low | M2_ENC_B
USART2 | PA2 | USART2_TX | Alternate Function Push Pull | Pull-up | Very High
*
| | | | | | USART_TX
| PA3 | USART2_RX | Alternate Function Push Pull | Pull-up | Very High
*
| | | | | | USART_RX
Single Mapped Signals | PC14- OSC32_IN | RCC_OSC32_IN | n/a | n/a | n/a
| PC15- OSC32_OU T | RCC_OSC32_O UT | n/a | n/a | n/a

PH0 -
OSC_IN
RCC_OSC_IN | n/a | n/a | n/a

PH1 -
OSC_OUT
RCC_OSC_OUT | n/a | n/a | n/a
PA13 | SYS_JTMS-
SWDIO
n/a | n/a | n/a | TMS
PA14 | SYS_JTCK-
SWCLK
n/a | n/a | n/a | TCK
PB3 | SYS_JTDO-
SWO
n/a | n/a | n/a | SWO
GPIO | PC13-
ANTI_TAMP

### GPIO_EXTI13 External Interrupt Mode with Falling edge trigger detection

No pull-up and no pull-down | n/a | B1 [Blue PushButton]
PC0 | GPIO_Input | Input mode | Pull-up * | n/a | B_BUMPER1
PC1 | GPIO_Input | Input mode | Pull-up * | n/a | B_BUMPER2
PA5 | GPIO_Output | Output Push Pull | No pull-up and no pull-down | Low | LD2 [Green Led]
PC10 | GPIO_Output | Output Push Pull | No pull-up and no pull-down | Low | US_TRIGGER
PC11 | GPIO_EXTI11 | | No pull-up and no pull-down | n/a | US_ECHO

IP | Pin | Signal | GPIO mode | GPIO pull/up pull down | Max Speed | User Label
| | | External Interrupt Mode with Rising/Falling edge
| PB4 | GPIO_Output | Output Push Pull | No pull-up and no pull-down | Low | M1_DIR
| PB5 | GPIO_Output | Output Push Pull | No pull-up and no pull-down | Low | M2_DIR

# 6.2. DMA configuration

## nothing configured in DMA service

# 6.3. NVIC configuration

Interrupt Table | Enable | Preenmption Priority | SubPriority
Non maskable interrupt | true | 0 | 0
Hard fault interrupt | true | 0 | 0
Memory management fault | true | 0 | 0
Pre-fetch fault, memory access fault | true | 0 | 0
Undefined instruction or illegal state | true | 0 | 0
System service call via SWI instruction | true | 0 | 0
Debug monitor | true | 0 | 0
Pendable request for system service | true | 0 | 0
System tick timer | true | 0 | 0
USART2 global interrupt | true | 0 | 0
EXTI line[15:10] interrupts | true | 0 | 0
PVD interrupt through EXTI line 16 | unused
Flash global interrupt | unused
RCC global interrupt | unused
TIM2 global interrupt | unused
TIM3 global interrupt | unused
TIM4 global interrupt | unused
TIM5 global interrupt | unused
FPU global interrupt | unused

### * User modified value

# 7. Power Consumption Calculator report

### 7.1. Microcontroller Selection

Series | STM32F4
Line | STM32F411
MCU | STM32F411RETx
Datasheet | 026289_Rev6

### 7.2. Parameter Selection

Temperature | 25
Vdd | null

# 8. Software Project

## 8.1. Project Settings

Name | Value
Project Name | mprojbot01
Project Folder | C:\Users\Adam\Documents\MyFiles\projects\mprojbot\firmware_stm\mprojbot01
Toolchain / IDE | TrueSTUDIO
Firmware Package Name and Version | STM32Cube FW_F4 V1.18.0

## 8.2. Code Generation Settings

Name | Value
STM32Cube Firmware Library Package | Copy only the necessary library files
Generate peripheral initialization as a pair of '.c/.h' files | No
Backup previously generated files when re-generating | No
Delete previously generated files when not re-generated | Yes
Set all free pins as analog (to optimize the power consumption) | No

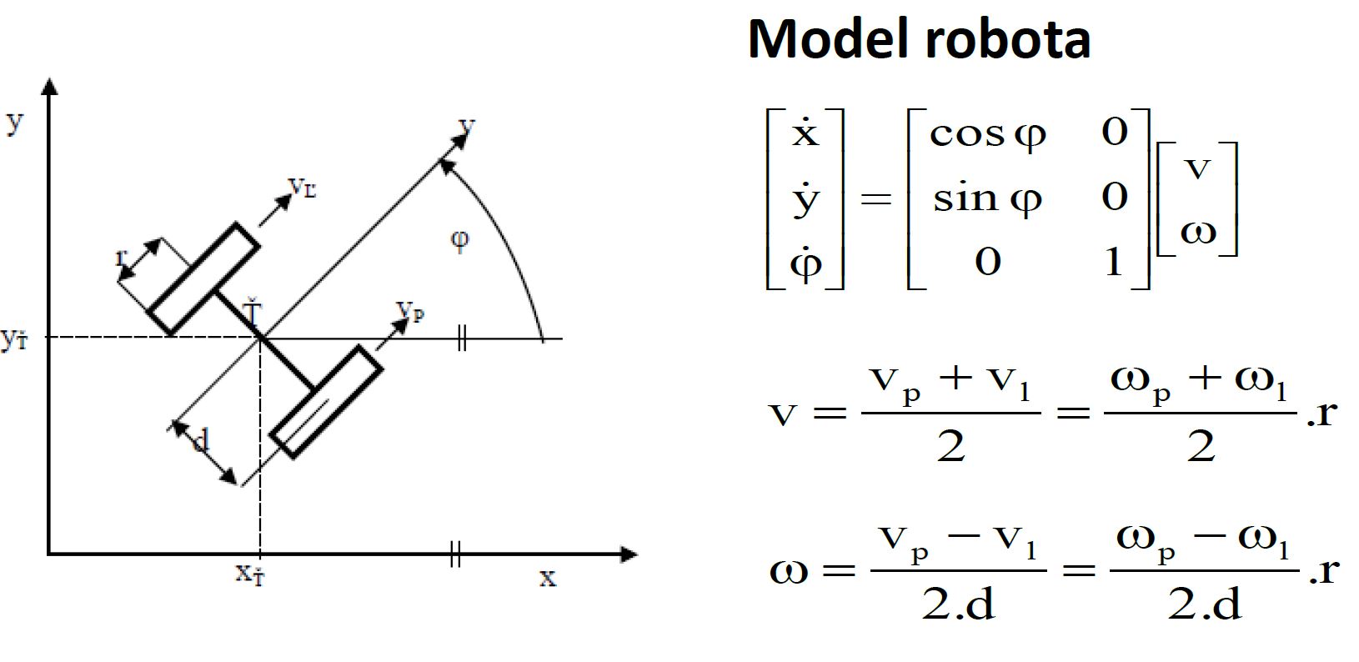
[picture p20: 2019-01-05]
doc/kinem1.JPG

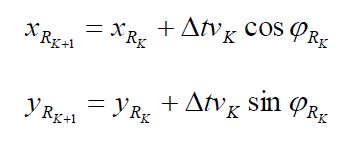
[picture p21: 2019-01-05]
doc/kinem4.JPG

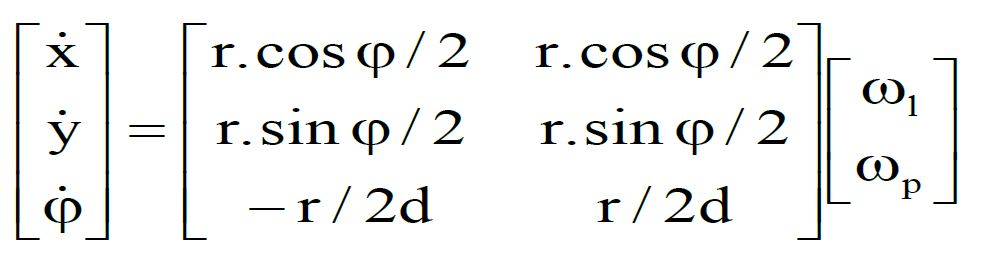
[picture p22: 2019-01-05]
doc/kinem2.JPG

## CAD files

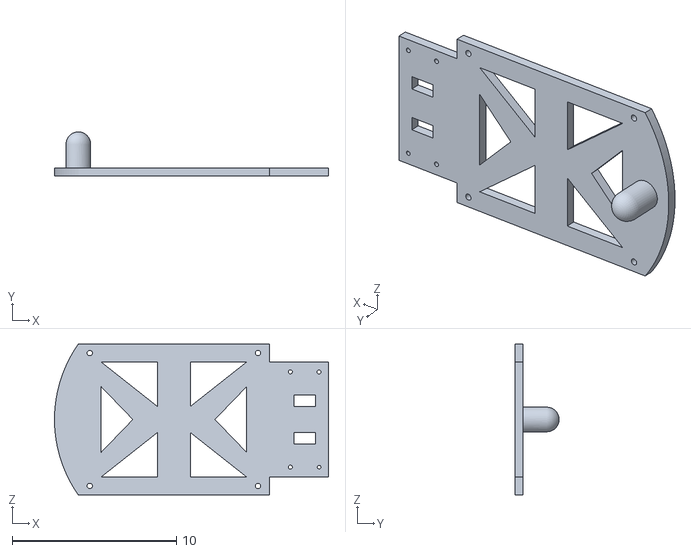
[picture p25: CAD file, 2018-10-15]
cad/mprojbot_podvozok v12.stl
16.7 x 2.70 x 9.20

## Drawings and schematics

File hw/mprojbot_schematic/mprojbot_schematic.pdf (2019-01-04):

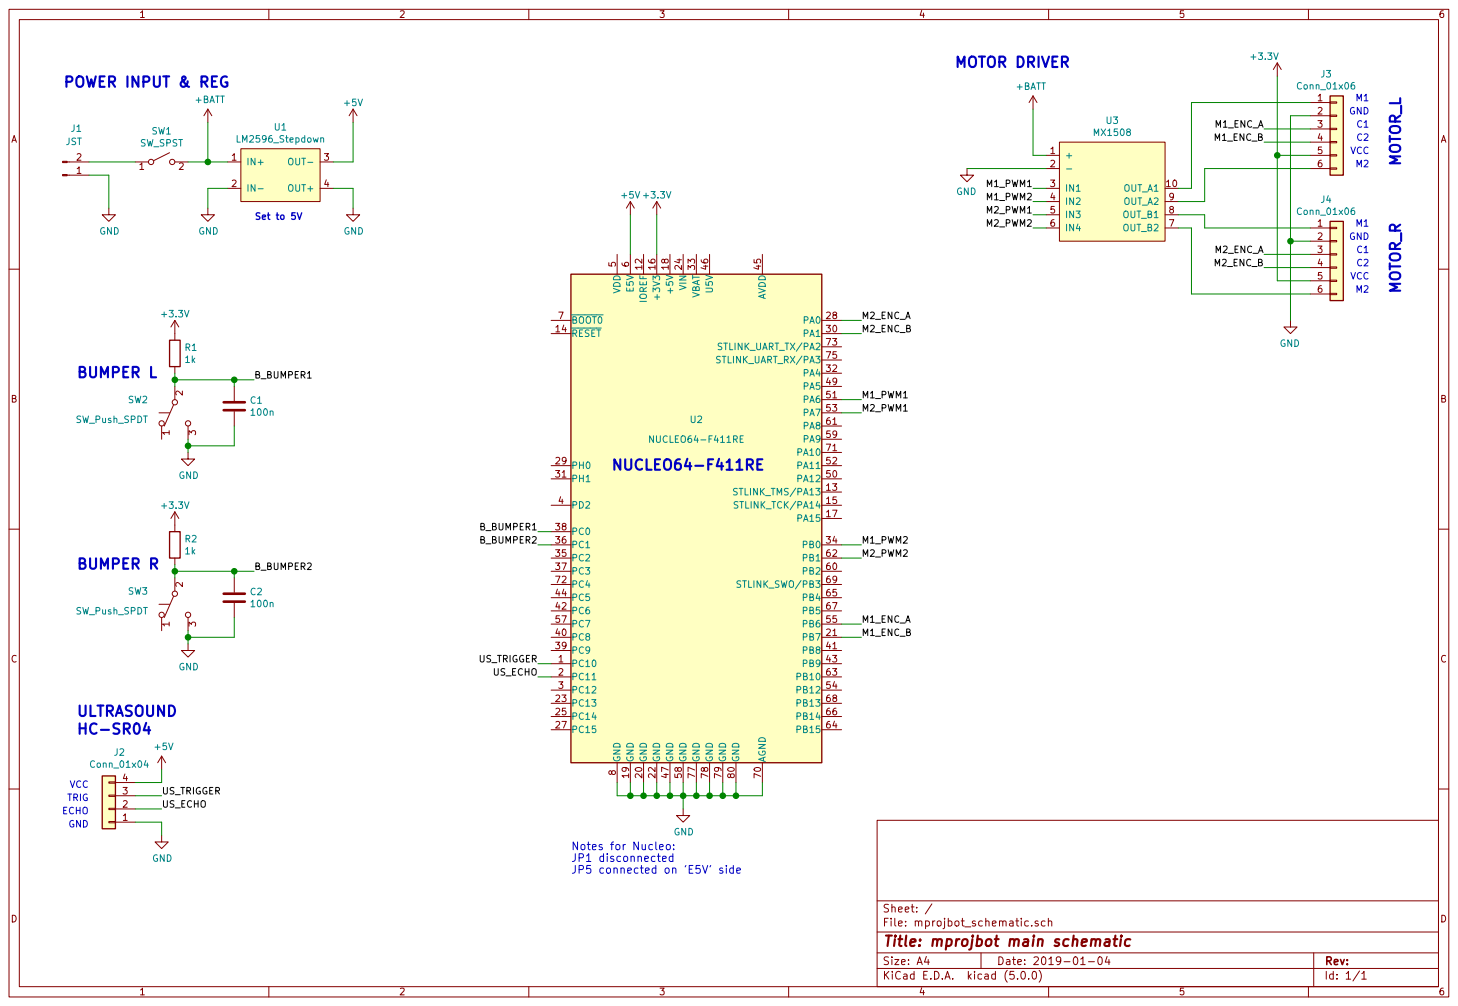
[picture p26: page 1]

Notes for Nucleo: JP1 disconnected
JP5 connected on 'E5V' side

Id: 1/1 Title: mprojbot main schematic

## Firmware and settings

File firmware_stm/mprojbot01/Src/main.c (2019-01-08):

/**
  ******************************************************************************
  * File Name          : main.c
  * Description        : Main program body
  ******************************************************************************
  ** This notice applies to any and all portions of this file
  * that are not between comment pairs USER CODE BEGIN and
  * USER CODE END. Other portions of this file, whether 
  * inserted by the user or by software development tools
  * are owned by their respective copyright owners.
  *
  * COPYRIGHT(c) 2019 STMicroelectronics
  *
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
  ******************************************************************************
  */

/* Includes ------------------------------------------------------------------*/
#include "main.h"
#include "stm32f4xx_hal.h"

/* USER CODE BEGIN Includes */
// !!!!!!!!  DOLEZITE PRE FUNKCNOST printf(): !!!!!!!!!
// !!!!!!!!  DOLEZITE PRE FUNKCNOST printf(): !!!!!!!!!
// !!!!!!!!  DOLEZITE PRE FUNKCNOST printf(): !!!!!!!!!
//	 Project Properties -> C/C++ Build->Settings-> Tool Settings-> C/C++ Linker-> General
//	 	 Runtime Library zmenit na "Newlib standard"
// 		 System calls zmenit na "Don't use syscalls from library"
//	 v src/ je potrebny subor syscalls.c. Ak tam nie je, rucne ho vytvorit a skopirovat obsah z
//	 https://github.com/fboris/STM32Cube_FW_F4/blob/master/Projects/STM32F429I-Discovery/Examples/BSP/TrueSTUDIO/syscalls.c
// !!!!!!!!  DOLEZITE PRE FUNKCNOST printf()  !!!!!!!!!

#include <stdio.h>

#include "uart.h"
#include "MotorControl.h"
#include "ultrasonic.h"
#include "commands.h"

/* USER CODE END Includes */

TIM_HandleTypeDef htim2;
TIM_HandleTypeDef htim3;
TIM_HandleTypeDef htim4;
TIM_HandleTypeDef htim5;

UART_HandleTypeDef huart2;

/* USER CODE BEGIN PV */

/* USER CODE END PV */

void SystemClock_Config(void);
static void MX_GPIO_Init(void);
static void MX_TIM5_Init(void);
static void MX_TIM4_Init(void);
static void MX_TIM3_Init(void);
static void MX_USART2_UART_Init(void);
static void MX_TIM2_Init(void);
static void MX_NVIC_Init(void);
                                    
void HAL_TIM_MspPostInit(TIM_HandleTypeDef *htim);
                                

/* USER CODE BEGIN PFP */

/* USER CODE END PFP */

int main(void)
{

  /* MCU Configuration----------------------------------------------------------*/

  /* Reset of all peripherals, Initializes the Flash interface and the Systick. */
  HAL_Init();

  /* Configure the system clock */
  SystemClock_Config();

  /* Initialize all configured peripherals */
  MX_GPIO_Init();
  MX_TIM5_Init();
  MX_TIM4_Init();
  MX_TIM3_Init();
  MX_USART2_UART_Init();
  MX_TIM2_Init();

  /* Initialize interrupts */
  MX_NVIC_Init();

  /* USER CODE BEGIN 2 */
  char msg[100];
  uint32_t counter = 0;
  volatile uint32_t c1 = 0;
  volatile uint32_t c2 = 0;
  int N = 5;
  int i = 0;
  float speeds[5] = {2, 5, 10, 15, 8};
  float setpoint = 2.0;
  uint32_t t_signal = HAL_GetTick();
  uint32_t t_sentUpdate = HAL_GetTick();


//  initMotors();
  initEncoders();
  initOdom();
  ultrasonicInit();
  motorCtrlInit();
  uartInit();

//  HAL_NVIC_SetPriority(USART2_IRQn, 0, 0);
//    HAL_NVIC_EnableIRQ(USART2_IRQn);
//  huart2.Instance->CR1 = USART_CR1_RE|USART_CR1_TE|USART_CR1_UE|USART_CR1_RXNEIE;


//  uint8_t motor = MOTOR_L;
//  printf("printf test\n");
//  uartPrintf("uartPrintf test\n");

  /* USER CODE END 2 */

  /* Infinite loop */
  /* USER CODE BEGIN WHILE */
  while (1)
  {
  /* USER CODE END WHILE */

  /* USER CODE BEGIN 3 */
//	  HAL_Delay(10);
	  HAL_GPIO_WritePin(LD2_GPIO_Port, LD2_Pin, 1);
	  uint32_t t = HAL_GetTick();

//	  uint16_t n = sprintf(msg, "It works %d!\r\n", counter);
//	  HAL_UART_Transmit(&huart2, (uint8_t*)msg, n, 100);
//	  uartPrintf("It works with custom printf %d!\r\n", counter);
//	  counter++;

	  ultrasonicStartMeasure();
	  float dist = ultrasonicGetDist();
	  int bumpL = HAL_GPIO_ReadPin(B_BUMPER1_GPIO_Port, B_BUMPER1_Pin);
	  int bumpR = HAL_GPIO_ReadPin(B_BUMPER2_GPIO_Port, B_BUMPER2_Pin);
//	  uartPrintf("%.2f\r\n", dist);

//	  if(t-t_signal > 5000){
//		  setpoint = speeds[((i++)%N)];
//		  t_signal = t;
//	  }
//	  motorCtrlSetpoint(-setpoint, setpoint);
//	  enableMotors(false);
//	  enableMotors(true);
//	  motorCtrlSetpoint(0, 0);

	  updateSerialRxCommand();
	  float v_x = 0.0;
	  float omega_z = 0.0;
	  getCmdvelCommand(&v_x, &omega_z);
	  motorCtrlSetpointCmdvel(v_x, omega_z);
//	  float setpointL = 0;
//	  float setpointR = 0;
//	  getCmdvelCommand(&setpointL, &setpointR);
	  /*
	  0.1,0.1
	  0.5,0.5
	   */
//	  motorCtrlSetpoint(setpointL, setpointR);

	  cmdvelWatchdogUpdate();

	  motorCtrlUpdate();

	  t = HAL_GetTick();
	  if(t - t_sentUpdate > 20){
		  // OdomX[float%.4f],OdomY[float%.4f],OdomRot[float%.4f],BumperL[0/1int],BumperR[0/1int],ultrasound[0..100int]\n"
		  uartPrintf("%.4f,%.4f,%.4f,%d,%d,%.2f\r\n", odomX, odomY, odomRot, bumpL, bumpR, dist);
		  t_sentUpdate = t;
	  }

	  HAL_GPIO_WritePin(LD2_GPIO_Port, LD2_Pin, 0);
  }
  /* USER CODE END 3 */

}

/** System Clock Configuration
*/
void SystemClock_Config(void)
{

  RCC_OscInitTypeDef RCC_OscInitStruct;
  RCC_ClkInitTypeDef RCC_ClkInitStruct;

    /**Configure the main internal regulator output voltage 
    */
  __HAL_RCC_PWR_CLK_ENABLE();

  __HAL_PWR_VOLTAGESCALING_CONFIG(PWR_REGULATOR_VOLTAGE_SCALE1);

    /**Initializes the CPU, AHB and APB busses clocks 
    */
  RCC_OscInitStruct.OscillatorType = RCC_OSCILLATORTYPE_HSI;
  RCC_OscInitStruct.HSIState = RCC_HSI_ON;
  RCC_OscInitStruct.HSICalibrationValue = 16;
  RCC_OscInitStruct.PLL.PLLState = RCC_PLL_ON;
  RCC_OscInitStruct.PLL.PLLSource = RCC_PLLSOURCE_HSI;
  RCC_OscInitStruct.PLL.PLLM = 8;
  RCC_OscInitStruct.PLL.PLLN = 100;
  RCC_OscInitStruct.PLL.PLLP = RCC_PLLP_DIV2;
  RCC_OscInitStruct.PLL.PLLQ = 4;
  if (HAL_RCC_OscConfig(&RCC_OscInitStruct) != HAL_OK)
  {
    _Error_Handler(__FILE__, __LINE__);
  }

    /**Initializes the CPU, AHB and APB busses clocks 
    */
  RCC_ClkInitStruct.ClockType = RCC_CLOCKTYPE_HCLK|RCC_CLOCKTYPE_SYSCLK
                              |RCC_CLOCKTYPE_PCLK1|RCC_CLOCKTYPE_PCLK2;
  RCC_ClkInitStruct.SYSCLKSource = RCC_SYSCLKSOURCE_PLLCLK;
  RCC_ClkInitStruct.AHBCLKDivider = RCC_SYSCLK_DIV1;
  RCC_ClkInitStruct.APB1CLKDivider = RCC_HCLK_DIV2;
  RCC_ClkInitStruct.APB2CLKDivider = RCC_HCLK_DIV1;

  if (HAL_RCC_ClockConfig(&RCC_ClkInitStruct, FLASH_LATENCY_3) != HAL_OK)
  {
    _Error_Handler(__FILE__, __LINE__);
  }

    /**Configure the Systick interrupt time 
    */
  HAL_SYSTICK_Config(HAL_RCC_GetHCLKFreq()/1000);

    /**Configure the Systick 
    */
  HAL_SYSTICK_CLKSourceConfig(SYSTICK_CLKSOURCE_HCLK);

  /* SysTick_IRQn interrupt configuration */
  HAL_NVIC_SetPriority(SysTick_IRQn, 0, 0);
}

/** NVIC Configuration
*/
static void MX_NVIC_Init(void)
{
  /* EXTI15_10_IRQn interrupt configuration */
  HAL_NVIC_SetPriority(EXTI15_10_IRQn, 0, 0);
  HAL_NVIC_EnableIRQ(EXTI15_10_IRQn);
}

/* TIM2 init function */
static void MX_TIM2_Init(void)
{

  TIM_ClockConfigTypeDef sClockSourceConfig;
  TIM_MasterConfigTypeDef sMasterConfig;

  htim2.Instance = TIM2;
  htim2.Init.Prescaler = 9;
  htim2.Init.CounterMode = TIM_COUNTERMODE_UP;
  htim2.Init.Period = 0xFFFFFFFF;
  htim2.Init.ClockDivision = TIM_CLOCKDIVISION_DIV1;
  if (HAL_TIM_Base_Init(&htim2) != HAL_OK)
  {
    _Error_Handler(__FILE__, __LINE__);
  }

  sClockSourceConfig.ClockSource = TIM_CLOCKSOURCE_INTERNAL;
  if (HAL_TIM_ConfigClockSource(&htim2, &sClockSourceConfig) != HAL_OK)
  {
    _Error_Handler(__FILE__, __LINE__);
  }

  sMasterConfig.MasterOutputTrigger = TIM_TRGO_RESET;
  sMasterConfig.MasterSlaveMode = TIM_MASTERSLAVEMODE_DISABLE;
  if (HAL_TIMEx_MasterConfigSynchronization(&htim2, &sMasterConfig) != HAL_OK)
  {
    _Error_Handler(__FILE__, __LINE__);
  }

}

/* TIM3 init function */
static void MX_TIM3_Init(void)
{

  TIM_MasterConfigTypeDef sMasterConfig;
  TIM_OC_InitTypeDef sConfigOC;

  htim3.Instance = TIM3;
  htim3.Init.Prescaler = 0;
  htim3.Init.CounterMode = TIM_COUNTERMODE_UP;
  htim3.Init.Period = 4096;
  htim3.Init.ClockDivision = TIM_CLOCKDIVISION_DIV1;
  if (HAL_TIM_PWM_Init(&htim3) != HAL_OK)
  {
    _Error_Handler(__FILE__, __LINE__);
  }

  sMasterConfig.MasterOutputTrigger = TIM_TRGO_RESET;
  sMasterConfig.MasterSlaveMode = TIM_MASTERSLAVEMODE_DISABLE;
  if (HAL_TIMEx_MasterConfigSynchronization(&htim3, &sMasterConfig) != HAL_OK)
  {
    _Error_Handler(__FILE__, __LINE__);
  }

  sConfigOC.OCMode = TIM_OCMODE_PWM1;
  sConfigOC.Pulse = 0;
  sConfigOC.OCPolarity = TIM_OCPOLARITY_HIGH;
  sConfigOC.OCFastMode = TIM_OCFAST_DISABLE;
  if (HAL_TIM_PWM_ConfigChannel(&htim3, &sConfigOC, TIM_CHANNEL_1) != HAL_OK)
  {
    _Error_Handler(__FILE__, __LINE__);
  }

  if (HAL_TIM_PWM_ConfigChannel(&htim3, &sConfigOC, TIM_CHANNEL_2) != HAL_OK)
  {
    _Error_Handler(__FILE__, __LINE__);
  }

  if (HAL_TIM_PWM_ConfigChannel(&htim3, &sConfigOC, TIM_CHANNEL_3) != HAL_OK)
  {
    _Error_Handler(__FILE__, __LINE__);
  }

  if (HAL_TIM_PWM_ConfigChannel(&htim3, &sConfigOC, TIM_CHANNEL_4) != HAL_OK)
  {
    _Error_Handler(__FILE__, __LINE__);
  }

  HAL_TIM_MspPostInit(&htim3);

}

/* TIM4 init function */
static void MX_TIM4_Init(void)
{

  TIM_Encoder_InitTypeDef sConfig;
  TIM_MasterConfigTypeDef sMasterConfig;

  htim4.Instance = TIM4;
  htim4.Init.Prescaler = 0;
  htim4.Init.CounterMode = TIM_COUNTERMODE_UP;
  htim4.Init.Period = 65535;
  htim4.Init.ClockDivision = TIM_CLOCKDIVISION_DIV1;
  sConfig.EncoderMode = TIM_ENCODERMODE_TI12;
  sConfig.IC1Polarity = TIM_ICPOLARITY_RISING;
  sConfig.IC1Selection = TIM_ICSELECTION_DIRECTTI;
  sConfig.IC1Prescaler = TIM_ICPSC_DIV1;
  sConfig.IC1Filter = 0;
  sConfig.IC2Polarity = TIM_ICPOLARITY_RISING;
  sConfig.IC2Selection = TIM_ICSELECTION_DIRECTTI;
  sConfig.IC2Prescaler = TIM_ICPSC_DIV1;
  sConfig.IC2Filter = 0;
  if (HAL_TIM_Encoder_Init(&htim4, &sConfig) != HAL_OK)
  {
    _Error_Handler(__FILE__, __LINE__);
  }

  sMasterConfig.MasterOutputTrigger = TIM_TRGO_RESET;
  sMasterConfig.MasterSlaveMode = TIM_MASTERSLAVEMODE_DISABLE;
  if (HAL_TIMEx_MasterConfigSynchronization(&htim4, &sMasterConfig) != HAL_OK)
  {
    _Error_Handler(__FILE__, __LINE__);
  }

}

/* TIM5 init function */
static void MX_TIM5_Init(void)
{

  TIM_Encoder_InitTypeDef sConfig;
  TIM_MasterConfigTypeDef sMasterConfig;

  htim5.Instance = TIM5;
  htim5.Init.Prescaler = 0;
  htim5.Init.CounterMode = TIM_COUNTERMODE_UP;
  htim5.Init.Period = 65535;
  htim5.Init.ClockDivision = TIM_CLOCKDIVISION_DIV1;
  sConfig.EncoderMode = TIM_ENCODERMODE_TI12;
  sConfig.IC1Polarity = TIM_ICPOLARITY_RISING;
  sConfig.IC1Selection = TIM_ICSELECTION_DIRECTTI;
  sConfig.IC1Prescaler = TIM_ICPSC_DIV1;
  sConfig.IC1Filter = 0;
  sConfig.IC2Polarity = TIM_ICPOLARITY_RISING;
  sConfig.IC2Selection = TIM_ICSELECTION_DIRECTTI;
  sConfig.IC2Prescaler = TIM_ICPSC_DIV1;
  sConfig.IC2Filter = 0;
  if (HAL_TIM_Encoder_Init(&htim5, &sConfig) != HAL_OK)
  {
    _Error_Handler(__FILE__, __LINE__);
  }

  sMasterConfig.MasterOutputTrigger = TIM_TRGO_RESET;
  sMasterConfig.MasterSlaveMode = TIM_MASTERSLAVEMODE_DISABLE;
  if (HAL_TIMEx_MasterConfigSynchronization(&htim5, &sMasterConfig) != HAL_OK)
  {
    _Error_Handler(__FILE__, __LINE__);
  }

}

/* USART2 init function */
static void MX_USART2_UART_Init(void)
{

  huart2.Instance = USART2;
  huart2.Init.BaudRate = 115200;
  huart2.Init.WordLength = UART_WORDLENGTH_8B;
  huart2.Init.StopBits = UART_STOPBITS_1;
  huart2.Init.Parity = UART_PARITY_NONE;
  huart2.Init.Mode = UART_MODE_TX_RX;
  huart2.Init.HwFlowCtl = UART_HWCONTROL_NONE;
  huart2.Init.OverSampling = UART_OVERSAMPLING_16;
  if (HAL_UART_Init(&huart2) != HAL_OK)
  {
    _Error_Handler(__FILE__, __LINE__);
  }

}

/** Configure pins as 
        * Analog 
        * Input 
        * Output
        * EVENT_OUT
        * EXTI
*/
static void MX_GPIO_Init(void)
{

  GPIO_InitTypeDef GPIO_InitStruct;

  /* GPIO Ports Clock Enable */
  __HAL_RCC_GPIOC_CLK_ENABLE();
  __HAL_RCC_GPIOH_CLK_ENABLE();
  __HAL_RCC_GPIOA_CLK_ENABLE();
  __HAL_RCC_GPIOB_CLK_ENABLE();

  /*Configure GPIO pin Output Level */
  HAL_GPIO_WritePin(LD2_GPIO_Port, LD2_Pin, GPIO_PIN_RESET);

  /*Configure GPIO pin Output Level */
  HAL_GPIO_WritePin(US_TRIGGER_GPIO_Port, US_TRIGGER_Pin, GPIO_PIN_RESET);

  /*Configure GPIO pin Output Level */
  HAL_GPIO_WritePin(GPIOB, M1_DIR_Pin|M2_DIR_Pin, GPIO_PIN_RESET);

  /*Configure GPIO pin : B1_Pin */
  GPIO_InitStruct.Pin = B1_Pin;
  GPIO_InitStruct.Mode = GPIO_MODE_IT_FALLING;
  GPIO_InitStruct.Pull = GPIO_NOPULL;
  HAL_GPIO_Init(B1_GPIO_Port, &GPIO_InitStruct);

  /*Configure GPIO pins : B_BUMPER1_Pin B_BUMPER2_Pin */
  GPIO_InitStruct.Pin = B_BUMPER1_Pin|B_BUMPER2_Pin;
  GPIO_InitStruct.Mode = GPIO_MODE_INPUT;
  GPIO_InitStruct.Pull = GPIO_PULLUP;
  HAL_GPIO_Init(GPIOC, &GPIO_InitStruct);

  /*Configure GPIO pin : LD2_Pin */
  GPIO_InitStruct.Pin = LD2_Pin;
  GPIO_InitStruct.Mode = GPIO_MODE_OUTPUT_PP;
  GPIO_InitStruct.Pull = GPIO_NOPULL;
  GPIO_InitStruct.Speed = GPIO_SPEED_FREQ_LOW;
  HAL_GPIO_Init(LD2_GPIO_Port, &GPIO_InitStruct);

  /*Configure GPIO pin : US_TRIGGER_Pin */
  GPIO_InitStruct.Pin = US_TRIGGER_Pin;
  GPIO_InitStruct.Mode = GPIO_MODE_OUTPUT_PP;
  GPIO_InitStruct.Pull = GPIO_NOPULL;
  GPIO_InitStruct.Speed = GPIO_SPEED_FREQ_LOW;
  HAL_GPIO_Init(US_TRIGGER_GPIO_Port, &GPIO_InitStruct);

  /*Configure GPIO pin : US_ECHO_Pin */
  GPIO_InitStruct.Pin = US_ECHO_Pin;
  GPIO_InitStruct.Mode = GPIO_MODE_IT_RISING_FALLING;
  GPIO_InitStruct.Pull = GPIO_NOPULL;
  HAL_GPIO_Init(US_ECHO_GPIO_Port, &GPIO_InitStruct);

  /*Configure GPIO pins : M1_DIR_Pin M2_DIR_Pin */
  GPIO_InitStruct.Pin = M1_DIR_Pin|M2_DIR_Pin;
  GPIO_InitStruct.Mode = GPIO_MODE_OUTPUT_PP;
  GPIO_InitStruct.Pull = GPIO_NOPULL;
  GPIO_InitStruct.Speed = GPIO_SPEED_FREQ_LOW;
  HAL_GPIO_Init(GPIOB, &GPIO_InitStruct);

}

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


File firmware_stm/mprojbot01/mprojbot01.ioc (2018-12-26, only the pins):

Mcu.UserName=STM32F411RETx
PA0-WKUP.GPIO_Label=M2_ENC_A
PA0-WKUP.Signal=S_TIM5_CH1
PA1.GPIO_Label=M2_ENC_B
PA1.Signal=S_TIM5_CH2
PA13.GPIO_Label=TMS
PA13.Signal=SYS_JTMS-SWDIO
PA14.GPIO_Label=TCK
PA14.Signal=SYS_JTCK-SWCLK
PA2.GPIO_Label=USART_TX
PA2.Signal=USART2_TX
PA3.GPIO_Label=USART_RX
PA3.Signal=USART2_RX
PA5.GPIO_Label=LD2 [Green Led]
PA5.Signal=GPIO_Output
PA6.GPIO_Label=M1_PWM1
PA6.Signal=S_TIM3_CH1
PA7.GPIO_Label=M2_PWM1
PA7.Signal=S_TIM3_CH2
PB0.GPIO_Label=M1_PWM2
PB0.Signal=S_TIM3_CH3
PB1.GPIO_Label=M2_PWM2
PB1.Signal=S_TIM3_CH4
PB3.GPIO_Label=SWO
PB3.Signal=SYS_JTDO-SWO
PB4.GPIO_Label=M1_DIR
PB4.Signal=GPIO_Output
PB5.GPIO_Label=M2_DIR
PB5.Signal=GPIO_Output
PB6.GPIO_Label=M1_ENC_A
PB6.Signal=S_TIM4_CH1
PB7.GPIO_Label=M1_ENC_B
PB7.Signal=S_TIM4_CH2
PC0.GPIO_Label=B_BUMPER1
PC0.Signal=GPIO_Input
PC1.GPIO_Label=B_BUMPER2
PC1.Signal=GPIO_Input
PC10.GPIO_Label=US_TRIGGER
PC10.Signal=GPIO_Output
PC11.GPIO_Label=US_ECHO
PC11.Signal=GPXTI11
PC13-ANTI_TAMP.GPIO_Label=B1 [Blue PushButton]
PC13-ANTI_TAMP.Signal=GPXTI13
PC14-OSC32_IN.Signal=RCC_OSC32_IN
PC15-OSC32_OUT.Signal=RCC_OSC32_OUT

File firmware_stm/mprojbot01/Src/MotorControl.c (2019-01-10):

/*
 * MotorControl.cpp
 *
 *  Created on: 3. 11. 2018
 *      Author: Adam
 */

#include "MotorControl.h"

//float motorKp = 1.0;
//float motorKi = 0.0;
//float motorKd = 0.0;

void initMotors(){

}

void initEncoders(){
	TIM4->CNT = 0;
	TIM5->CNT = 0;
	HAL_TIM_Encoder_Start(&htim4, TIM_CHANNEL_ALL);
	HAL_TIM_Encoder_Start(&htim5, TIM_CHANNEL_ALL);
}

void initOdom(){
	setOdom(0, 0, 0);
}

void enableMotors(bool enable){
	motorsEnabled = enable;
}

void setMotor(uint8_t motor, float speed){
	// speed <-1;1> = <-20;20> rad/s
	if (speed > 1.0f)
		speed = 1.0f;
	else if (speed < -1.0f)
		speed = -1.0f;

	if (speed >= 0){
		setMotorPWM(motor, DIR_FWD, speed*PWM_MAX);
	}
	else {
		setMotorPWM(motor, DIR_REV, -1*speed*PWM_MAX);
	}
}

/*
 * MX1508 control table
 * https://forums.parallax.com/discussion/168432/h-bridges-of-madison-county-77-cents
 * 			IN1		IN2
 *  FWD	   1/PWM     0
 *  REV		 0     1/PWM
 * IDLE      0       0
 * BRAKE     1       1
 */
void setMotorPWM(uint8_t motor, uint8_t direction, uint32_t pwm){
	if (pwm > PWM_MAX)
		pwm = PWM_MAX;

	TIM_OC_InitTypeDef sConfigA, sConfigB;
	sConfigA.OCMode = TIM_OCMODE_PWM1;
	sConfigA.OCPolarity = TIM_OCPOLARITY_HIGH;
	sConfigA.OCFastMode = TIM_OCFAST_DISABLE;
	sConfigB.OCMode = TIM_OCMODE_PWM1;
	sConfigB.OCPolarity = TIM_OCPOLARITY_HIGH;
	sConfigB.OCFastMode = TIM_OCFAST_DISABLE;

	if (pwm == 0) {
		sConfigA.Pulse = 0;
		sConfigB.Pulse = 0;
	}
	else if (direction == DIR_FWD) {
		sConfigA.Pulse = PWM_MAX-pwm;
		sConfigB.Pulse = PWM_MAX;
	}
	else if (direction == DIR_REV) {
		sConfigA.Pulse = PWM_MAX;
		sConfigB.Pulse = PWM_MAX-pwm;
	}

	uint32_t channelA = TIM_CHANNEL_1;
	uint32_t channelB = TIM_CHANNEL_3;
	if (motor == MOTOR_L){
		channelA = TIM_CHANNEL_1;
		channelB = TIM_CHANNEL_3;
	}
	else {
		// Right motor is reversed
		channelA = TIM_CHANNEL_4;
		channelB = TIM_CHANNEL_2;
	}

	if (   HAL_TIM_PWM_ConfigChannel(&htim3, &sConfigA, channelA) != HAL_OK
		|| HAL_TIM_PWM_Start(&htim3, channelA) != HAL_OK)
	{
		_Error_Handler(__FILE__, __LINE__);
	}

	if (   HAL_TIM_PWM_ConfigChannel(&htim3, &sConfigB, channelB) != HAL_OK
			|| HAL_TIM_PWM_Start(&htim3, channelB) != HAL_OK)
	{
		_Error_Handler(__FILE__, __LINE__);
	}

}

void motorCtrlInit(){
	motorsEnabled = false;
	encL = TIM4->CNT;
	encR = TIM5->CNT;
	encLPrev = encL;
	encRPrev = encR;
	motorIntegratorL = 0;
	motorIntegratorR = 0;
	motorSetpointL = 0;
	motorSetpointR = 0;
	motorEL = 0;
	motorER = 0;
	motorEPrevL = 0;
	motorEPrevR = 0;
	motorCtrlLastUpdate = HAL_GetTick();
	motorCtrlCounter = 0;
}

void motorCtrlUpdate(){
	uint32_t t = HAL_GetTick();
	// Rate limit
	if((t - motorCtrlLastUpdate)<motorCtrlRateDt){
		return;
	}

	// Calculate & limit delta time
	float dt = (t - motorCtrlLastUpdate)*0.001;
	if(dt>0.1)
		dt = 0.1;
	else if(dt<0.001) // avoid div 0
		dt = 0.001;

	encLPrev = encL;
	encRPrev = encR;
	encL = TIM4->CNT;
	encR = TIM5->CNT;
	int32_t dencL = encLPrev - encL;
	int32_t dencR = encRPrev - encR;
	if(dencR < -40000)  // Handle encoder counter overflow
		dencR = 65535 + dencR;
	else if(dencR > 40000)
		dencR = 65535 - dencR;
	if(dencL < -40000)
		dencL = 65535 + dencL;
	else if(dencL > 40000)
		dencL = 65535 - dencL;

	volatile float speedL = -1.0*(float)dencL*enc2omega/dt; // speed [rad/s]
	volatile float speedR =  1.0*(float)dencR*enc2omega/dt;

	odomUpdate(speedL, speedR, dt);

	motorEPrevL = motorEL;
	motorEPrevR = motorER;
	// Error
	motorEL = motorSetpointL - speedL;
	motorER = motorSetpointR - speedR;
	// Derivative
	float dEL = (motorEPrevL - motorEL)/dt;
	float dER = (motorEPrevR - motorER)/dt;
	// Integral + integrator clamping
	motorIntegratorL += motorKi * motorEL * dt;
	motorIntegratorR += motorKi * motorER * dt;
	if(motorIntegratorL > motorIntegratorMax)
		motorIntegratorL = motorIntegratorMax;
	else if(motorIntegratorL < -motorIntegratorMax)
		motorIntegratorL = -motorIntegratorMax;
	if(motorIntegratorR > motorIntegratorMax)
		motorIntegratorR = motorIntegratorMax;
	else if(motorIntegratorR < -motorIntegratorMax)
		motorIntegratorR = -motorIntegratorMax;
	// PID magic
	// Calculate control effort u=<-1;1>
	float uL = motorKp*motorEL + motorIntegratorL + motorKd*dEL;
	float uR = motorKp*motorER + motorIntegratorR + motorKd*dER;

	if(motorsEnabled){
		setMotor(MOTOR_L, uL);
		setMotor(MOTOR_R, uR);
	}
	else{
		// Important: zero the integrators!
		motorIntegratorL = 0;
		motorIntegratorR = 0;
		setMotor(MOTOR_L, 0);
		setMotor(MOTOR_R, 0);
	}

//	if((motorCtrlCounter++) % 10 == 0){
//		uartPrintf("%.4f %.4f %.4f %.3f %.3f\r\n", dt, motorEL, motorER, uL, uR);
//	}
//	uartPrintf("%ld %ld\r\n", dencL, dencR);
	if((motorCtrlCounter++) % 5 == 0){
	//	uartPrintf("%.4f %.4f %.3f\r\n", dt, motorER, uR);
//		uartPrintf("%ld %ld\r\n", encL, encR);
//		uartPrintf("%ld %ld\r\n", dencL, dencR);
//		uartPrintf("%.4f %.4f %.4f %.4f %.3f\r\n", dt, motorER, dER, motorIntegratorR, uR);
//		uartPrintf("%.4f %.4f %.4f %.3f\r\n", speedR, motorER, motorIntegratorR, uR);
//		uartPrintf("%.4f %.4f %.4f %.4f %.4f\r\n", speedL, speedR, odomX, odomY, odomRot);
//		uartPrintf("%.4f %.4f %.4f\r\n", odomX, odomY, odomRot);
	}
	motorCtrlLastUpdate = t;
}

void motorCtrlSetpoint(float omega_l, float omega_r){
	motorSetpointL = clamp(-omega_l, WHEEL_OMEGA_MAX);
	motorSetpointR = clamp(omega_r, WHEEL_OMEGA_MAX);
}

void motorCtrlSetpointCmdvel(float v_x, float omega_z){
	v_x = clamp(v_x, CMDVEL_VX_MAX);
	omega_z = clamp(omega_z, CMDVEL_OMEGA_MAX);
	float wl = -(v_x-wheel_d*omega_z/2.0)/wheel_R;
	float wr = (v_x+wheel_d*omega_z/2.0)/wheel_R;
//	uartPrintf("cmdvel %f %f\r\n", wl, wr);
	motorCtrlSetpoint(wl, wr);
}

void setOdom(float oX, float oY, float oRot){
	odomX = oX;
	odomY = oY;
	odomRot = oRot;
}

void odomUpdate(float wl, float wr, float dt){
	float v_k = (wl+wr)*wheel_R;
	float odomRotPrev = odomRot;
	odomRot += (wr-wl)*(wheel_R/wheel_d)*dt;
	// TODO: Yaw clamping to +-PI


	if(wl==wr){
		odomX += v_k*cos(odomRot)*dt;
		odomY += v_k*sin(odomRot)*dt;
	}
	else{
		float vl = wl*wheel_R;
		float vr = wr*wheel_R;
		float frac = (wheel_d/2)*((vr+vl)/(vr-vl));
		odomX -= frac*(cos(odomRot)-cos(odomRotPrev));
		odomY += frac*(sin(odomRot)-sin(odomRotPrev));
	}
}

float clamp(float value, float limit){
	if(value > limit)
		return limit;
	else if(value < -limit){
		return -limit;
	}
	else {
		return value;
	}
}

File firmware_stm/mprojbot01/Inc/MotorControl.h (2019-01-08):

/*
 * MotorControl.h
 *
 *  Created on: 3. 11. 2018
 *      Author: Adam
 */

#ifndef MOTORCONTROL_H_
#define MOTORCONTROL_H_

#include "inttypes.h"
#include "stdbool.h"
#include "stm32f4xx_hal.h"

//#include "main.h"
#include "math.h"
#include "uart.h"
#include "commands.h"

#define MOTOR_L 0
#define MOTOR_R 1
#define DIR_FWD 0
#define DIR_REV 1

#define PWM_MAX 4096
#define WHEEL_OMEGA_MAX 20.0f
#define CMDVEL_VX_MAX 0.3f
#define CMDVEL_OMEGA_MAX 3.5

extern TIM_HandleTypeDef htim3;
extern TIM_HandleTypeDef htim4;
extern TIM_HandleTypeDef htim5;

volatile uint32_t encL;
volatile uint32_t encR;
volatile uint32_t encLPrev;
volatile uint32_t encRPrev;

// Control
static int motorCtrlRateDt = 1000/250; // ms / Hz = ms
static float motorKp = 0.3;  //0.2
static float motorKi = 0.55; //0.025
static float motorKd = 0.0005; // 0
static float motorIntegratorMax = 1;
// 7cpr encoder * 4x sampling = 28 pulses / motor rev * 100:1 gear
static float wheelCPR = (4*7*100);
static float enc2omega = (2*M_PI)/(4*7*100);
float motorIntegratorL;
float motorIntegratorR;
float motorSetpointL; // motor setpoint [rad/s]
float motorSetpointR;
float motorEL;
float motorER;
float motorEPrevL;
float motorEPrevR;
uint32_t motorCtrlLastUpdate;
uint32_t motorCtrlCounter;
static bool motorsEnabled = false;

// Odom
static float wheel_R = 0.0341/2.0; // wheel radius [m]
static float wheel_d = 0.09425;  //wheel distance [m]
float odomX;
float odomY;
float odomRot;


void initMotors();
void initEncoders();
void initOdom();

void enableMotors(bool enable);
void setMotor(uint8_t motor, float speed);
void setMotorPWM(uint8_t motor, uint8_t direction, uint32_t pwm);

void motorCtrlInit();
void motorCtrlUpdate();
void motorCtrlSetpoint(float omega_l, float omega_r);
void motorCtrlSetpointCmdvel(float v_x, float omega_z);

void setOdom(float oX, float oY, float oRot);
void odomUpdate(float wl, float wr, float dt);

float clamp(float value, float limit);

#endif /* MOTORCONTROL_H_ */

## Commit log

2018-10-15 Add chassis CAD model
    [mprojbot_podvozok v12.stl]
2018-10-18 Add STM32CubeMX reports
2018-11-03 Add ENC pin labels, add motor dir pins
2018-11-03 Test motor pwm code
2018-11-03 Try adding UART printf
2018-11-10 Motor PWM v1 (not successful)
    need to change driving method for MX1508
2018-11-10 Fix PWM, begin encoders
    [MotorControl.c, MotorControl.h, main.c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]
2018-12-09 Basic motor PID ctrl attempt
    + log data
2018-12-26 Motor PID working
2018-12-26 Add ultrasonic sensor
2018-12-27 Basic odometry (needs tweaking & testing)
2018-12-27 Send status @50Hz, main cleanup
2019-01-04 Add schematics
    [mprojbot_schematic.kicad_pcb, mprojbot_schematic.sch]
2019-01-07 Basic UART cmdvel receiving
    todo: convert from cmdvel to L/R speed
2019-01-08 FW: TODO Fix odom rotation
    [MotorControl.c]

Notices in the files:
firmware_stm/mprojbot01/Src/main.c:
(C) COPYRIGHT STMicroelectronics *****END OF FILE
